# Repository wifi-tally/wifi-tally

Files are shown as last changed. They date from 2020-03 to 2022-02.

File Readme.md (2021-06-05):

# Open Source Tally Light

vTally is an Open Source Wifi Tally Light based on the ESP8266.

It aims to be affordable without sacrificing reliability and works with most
common video mixers.

Its architecture uses a central Hub that connects the tallies to the video mixer and
allows easy configuration and monitoring.

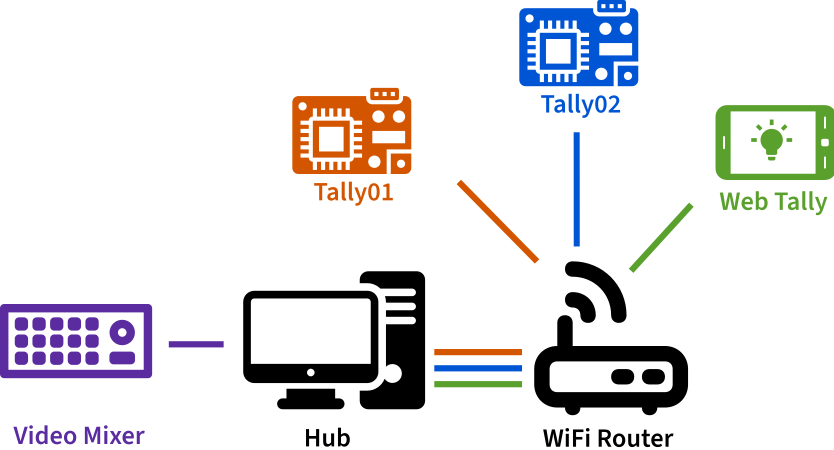
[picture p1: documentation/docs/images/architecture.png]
Architecture Setup

uses icons from the Noun Project by 
[Eucalyp](https://thenounproject.com/browse/?i=3151803),
[Atif Arshad](https://thenounproject.com/browse/?i=1294543),
[priyanka](https://thenounproject.com/browse/?i=1637910),
[Hrbon](https://thenounproject.com/browse?i=3014911) and
[ProSymbols](https://thenounproject.com/browse/?i=1086042), all licensed [CC-BY-3.0](https://creativecommons.org/licenses/by/3.0/us/legalcode)

## Features

* WiFi Tally Light based on the ESP8266
* Hardware costs of about 10€
* flexible USB power (battery pack, camera outlet, stationary)
* Fast communication and lightweight protocol
* uses a central Hub to communicate, that allows easy monitoring
* utilizes your local network and access points
* support for RGB Leds (anode, cathode), WS2812, NeoPixel, etc
* alternatively: turn any device with a browser (smartphone, tablet) into a Tally
* Open Source / Open Hardware

## Getting Started

:arrow_forward: :arrow_forward: :arrow_forward: [Read the full documentation at wifi-tally.github.io](https://wifi-tally.github.io/) :arrow_backward: :arrow_backward: :arrow_backward:

## Status







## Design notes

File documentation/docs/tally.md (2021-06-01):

# Tally

## tally-settings.ini Reference

| setting name | default | description |
| --- | --- | --- |
| `station.ssid` | **(required)** |The name of the WiFi that the Tally should connect to |
| `station.password` | (none) | The password to connect to the WiFi. If the WiFi has no password, leave it empty. |
| `hub.ip` | **(required)** | The IP address the hub is running on |
| `hub.port` | `{{ tally_default_port }}` | The port where the hub listens. |
| `tally.name` | (chip id) | How you want _this_ tally to be labeled in the hub. This name needs to be unique amongst all tallies in your network. It must not be longer than `26` characters. Use of ASCII characters is recommended. |
| `operator.type` | `grb+` | How the pins for the operator light are driven. Use `grb+` when a `high` state signalizes _off_ and `grb-` when a `low` state signalizes _off_. |
| `operator.ws2812` | `5 grb` | Number of WS2812 like LEDs in a strip that serve as operator lights. Has to be a number between `0` and `10`, followed by the order of the colors (`grb` or `rgb`). The operator lights are the first in the strip, followed by the stage lights. |
| `stage.type` | `grb+` | How the pins for the stage light are driven. Use `grb+` when a `high` state signalizes _off_ and `grb-` when a `low` state signalizes _off_. |
| `stage.ws2812` | `0 grb` | Number of WS2812 like LEDs in a strip that serve as stage lights. Has to be a number between `0` and `10`, followed by the order of the colors (`grb` or `rgb`). The stage  lights come right after the operator lights in the strip. |

## Using WS2812, NeoPixel, etc

WS2812-compatible LED strips come with many names. Most common are `WS2812b` and `NeoPixel`. If you have
anything that says it is compatible with either of those, it will probably work.

Connect the strip to pin `D4`, the `+5V` and `GND` respectively.

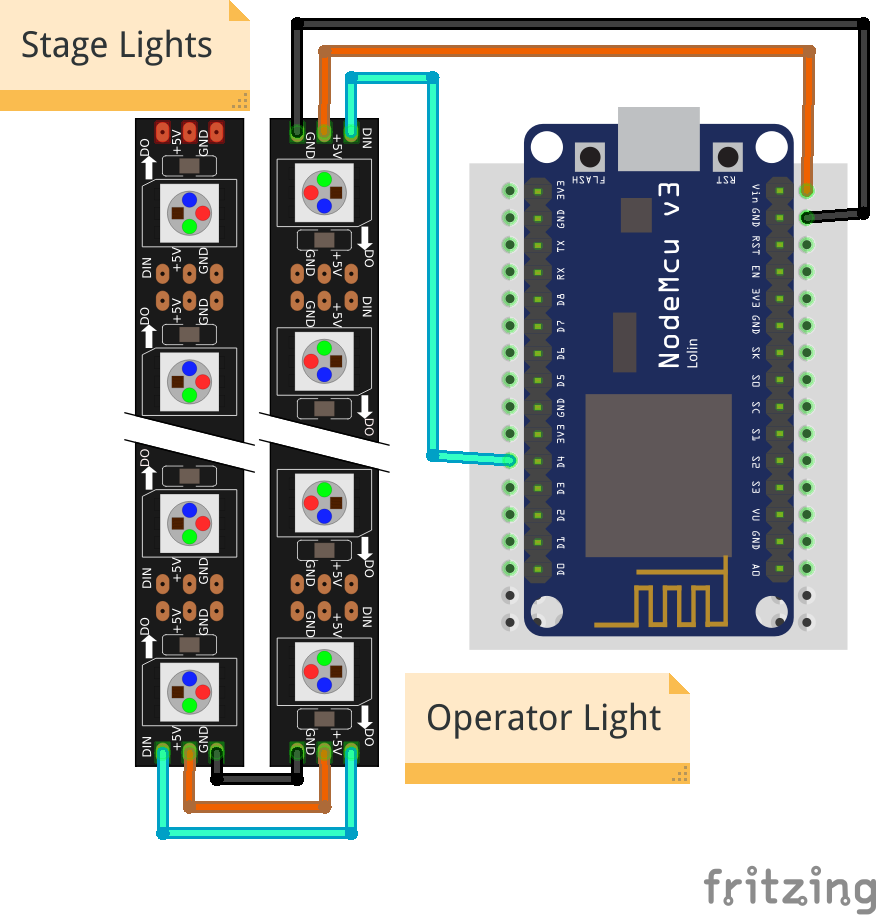
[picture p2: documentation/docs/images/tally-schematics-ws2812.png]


By default the first `5` pixels in the strip will work as Operator Lights, the others stay dark.

The number of LEDs you want to use as Operator Lights and Stage Lights can be configured in 
`tally-settings.ini` with the `operator.ws2812` and `stage.ws2812` settings.

In the example above, the correct configuration to drive 4 Operator Lights and 4 Stage Lights
would be

````ini
operator.ws2812 = 4
stage.ws2812    = 4
````

!!! info "Order of LED lights"
    When wiring, please note, that the Operator Lights always come _before_ the Stage Lights.

It is also possible to combine WS2812 strips and RGB Leds in one setup as all pins are driven
simultaneously. You could, for instance use a single RGB LED as the operator light and a
WS2812 strip for the stage light.

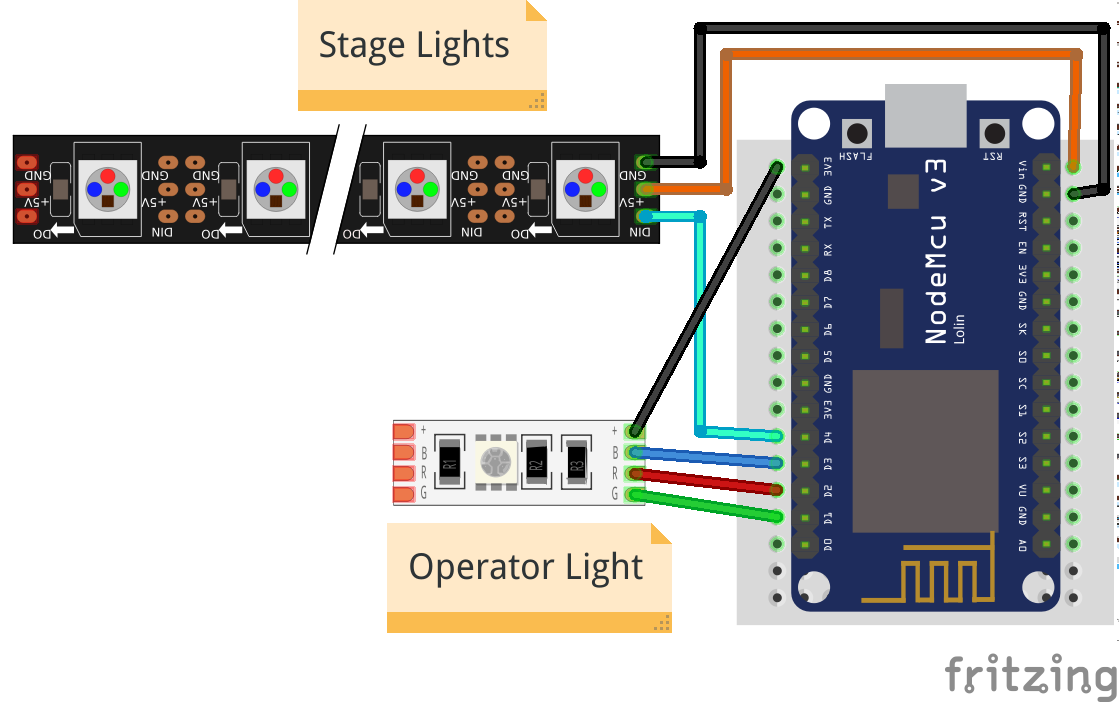
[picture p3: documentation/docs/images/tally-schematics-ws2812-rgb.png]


The configuration for this example would be

````ini
operator.ws2812 = 0
stage.ws2812    = 4
````

## Using LEDs with common cathode

You can use an LED with a common cathode with the tally. First connect the common pin
to `GND` instead of `3V3` and then configure `tally-settings.ini` to drive the pins correctly.
If you skip this step the colors that should be on are off, and vice versa.

````ini
operator.type = grb-
stage.type    = grb-
````

You can also mix different RGB Led types for the Operator and Stage Light.

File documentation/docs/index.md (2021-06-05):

# Open Source Tally Light

vTally is an Open Source Wifi Tally Light based on the ESP8266.

It aims to be affordable without sacrificing reliability and works with most
common video mixers.

Its architecture uses a central Hub that connects the tallies to the video mixer and
allows easy configuration and monitoring.

Architecture Setup
<span style="font-size:smaller;opacity:0.8">uses icons from the Noun Project by 
[Eucalyp](https://thenounproject.com/browse/?i=3151803),
[Atif Arshad](https://thenounproject.com/browse/?i=1294543),
[priyanka](https://thenounproject.com/browse/?i=1637910),
[Hrbon](https://thenounproject.com/browse?i=3014911) and
[ProSymbols](https://thenounproject.com/browse/?i=1086042), all licensed [CC-BY-3.0](https://creativecommons.org/licenses/by/3.0/us/legalcode)</span>

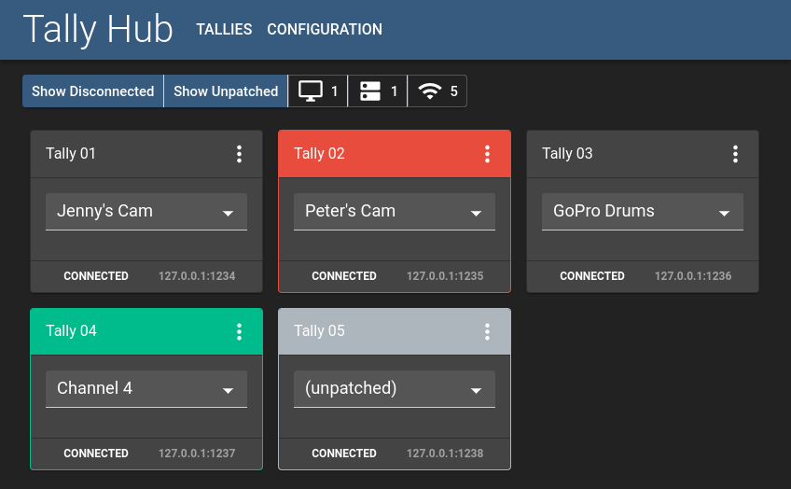
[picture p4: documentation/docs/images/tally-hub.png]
Tally Hub


## Features

* WiFi Tally Light based on the ESP8266
* Hardware costs of about 10€
* flexible USB power (battery pack, camera outlet, stationary)
* Fast communication and lightweight protocol
* uses a central Hub to communicate, that allows easy monitoring
* utilizes your local network and access points
* support for RGB Leds (anode, cathode), WS2812, NeoPixel, etc
* alternatively: turn any device with a browser (smartphone, tablet) into a Tally
* Open Source / Open Hardware

## Supported Video Mixers

* [Blackmagic Design ATEM](https://www.blackmagicdesign.com/products)
* [OBS Studio](https://obsproject.com/)
* [Roland V-8HD](https://proav.roland.com/de/products/v-8hd/), [Roland V-60HD](https://proav.roland.com/de/products/v-60hd/), and maybe others
* [vMix](https://www.vmix.com/software/)

!!! info
    Please [open an issue](https://github.com/wifi-tally/wifi-tally/issues)
    if you want others to be supported too. It is really simple to integrate them
    and the only reason they have not been integrated yet, is that nobody has needed it already. :D

## Get Started

Refer to [Getting Started](getting-started/index.md) to start running your own vTally setup.

## Download

See the [download page](download.md).

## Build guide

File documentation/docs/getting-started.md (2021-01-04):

# Getting started

You need two parts to get the Tally Light operational: The Tally Lights themselves
and the Hub that connects your video mixer and the Tallies.

Architecture Setup
<span style="font-size:smaller;opacity:0.8">uses icons from the Noun Project by 
[Eucalyp](https://thenounproject.com/browse/?i=3151803),
[Atif Arshad](https://thenounproject.com/browse/?i=1294543),
[Hrbon](https://thenounproject.com/browse?i=3014911) and
[ProSymbols](https://thenounproject.com/browse/?i=1086042), all licensed [CC-BY-3.0](https://creativecommons.org/licenses/by/3.0/us/legalcode)</span>

## Things you need

### a trusted network that allows access via WiFi
  
Your video mixer, the Hub and the Tallies need to be able to connect to each other.
You should take care that there is a close and stable WiFi hotspot near your Tallies
for obvious reasons. The network you are using should be trusted as all communication
is unencrypted.

The WiFi Chip supports `IEEE 802.11 b/g/n` and operates in the `2.4GHz` frequency band.
The Wifi network should support that as well.

### a computer to run the Hub on
  
The application is rather light weight, so there are no special requirements here
and it could run other applications in parallel. The Hub has a web interface for
monitoring and configuration that can be shown on any browser that can connect to
the computer.

To keep latency to a minimum it would be perfect if this computer uses a wired
connection.
  
### a NodeMcu ESP8266
  
This is an ESP8266 wifi chip on a development board that is typically used for IoT
applications. As it is an Open Hardware project there are lots of different boards
available. They mostly differ in price and form factor and are all fit for the project.
But they all look similar to this:

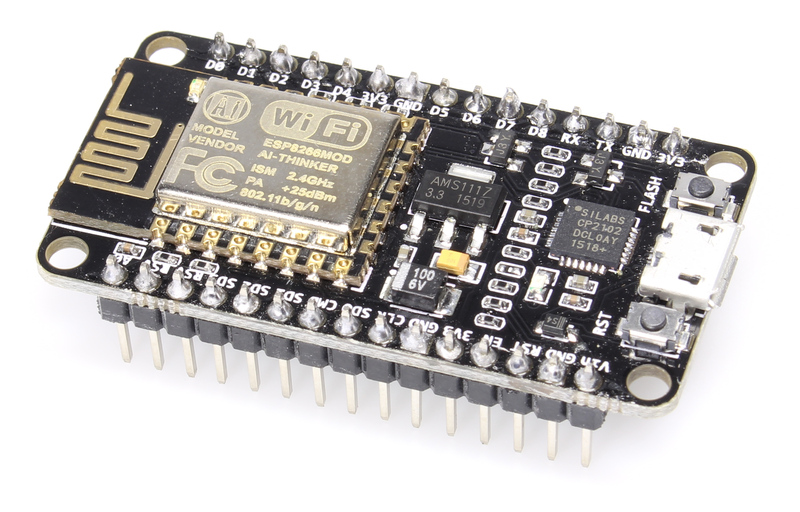
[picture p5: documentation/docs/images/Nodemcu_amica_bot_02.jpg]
Photography of a NodeMCU


["NodeMCU Amica"](https://commons.wikimedia.org/wiki/File:Nodemcu_amica_bot_02.png) 
by "Make Magazin DE", [CC-BY-SA-4.0](https://creativecommons.org/licenses/by-sa/4.0/deed.en)

!TODO: elaborate on different NodeMCUs!
  
### a piece of RGB LED strip
  
It needs to be specified for 5V and have a common anode.
Most LED strips that can be separated after _every_ LED and have 4 pins should fulfill that requirement. 

I recommend taking one with 120LEDs per meter to not have the LEDS be spaced too much.

### an USB power source

The whole setup draws far less than `200mA` and can be powered via USB.

* Some cameras have USB outlets that you can use
* `200mA` is little enough that even the smallest power bank can supply the Tally for hours
* use any old USB charger

## Setup

Running the tally lights consists of two steps:

* **Setup the Tally Light** This means connecting the hardware and flashing the software onto it.

* **Setup the Hub** This is the piece of software that communicates with your video mixer and all
  connected Tallies and runs on any computer you provide.

### Download sources

The latest releases can be found on [github.com/wifi-tally]({{ github_link }}/releases).

### Setting up the Tally

#### Connect the hardware

All you need to do is connecting the LED strip to the NodeMCU board.

!!! warning
    Do not connect more than 5 LEDs to the board!
    
    This will drain too much current through the board and potentially damaging it.

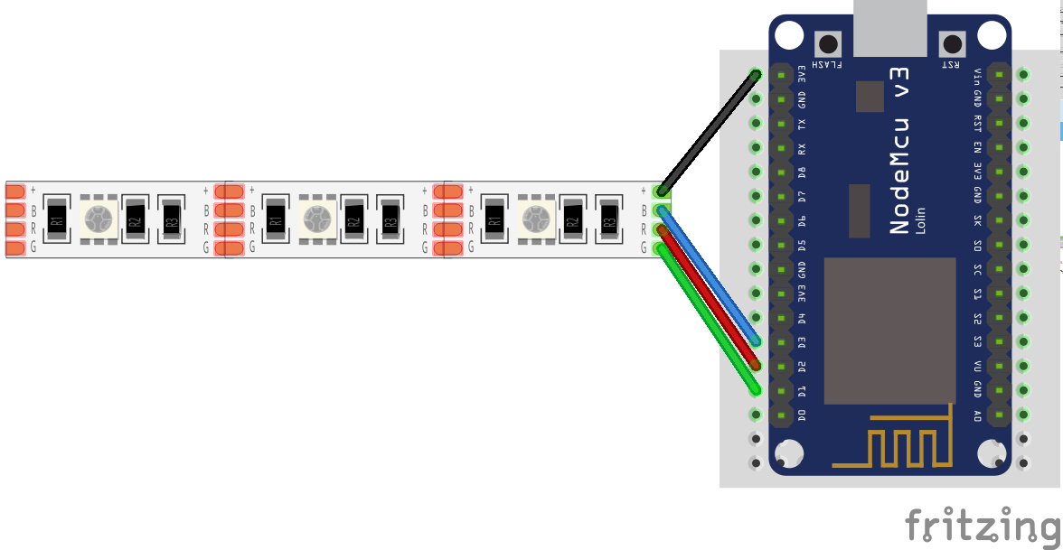
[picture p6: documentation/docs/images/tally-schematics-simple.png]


| board PIN | strip PIN |
| --- | --- |
| D3 | B |
| D2 | R |
| D1 | G |
| 3V3 | + or +5V |

!!! info
    It is possible to connect the `+5V` pin of the LED strip to `Vin` on the board. But not all NodeMCU boards connect
    the PIN to the USB power supply and your LEDs would stay dark.
    
    It might also happen that you LED Strip does not work with a lower voltage of the 3.3V output. Typically this does
    not happen, but it could if you have an older strips.

This is how the setup could look like on a breadboard.

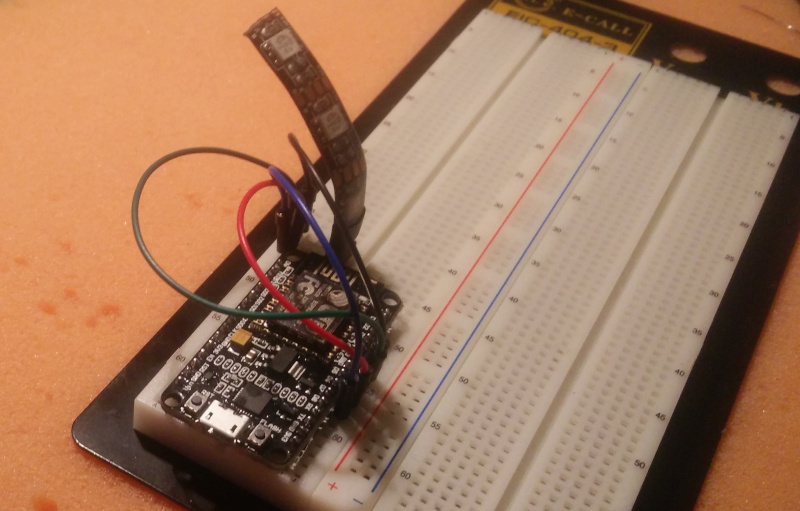
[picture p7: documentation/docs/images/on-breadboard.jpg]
WiFi Tally on a breaboard


##### Separate Operator and Stage Light

You can connect a second strip to use as an indicator for the speaker on stage.
Connect the first LED as above and direct it in the direction of the camera operator.
Then connect a second strip and let it face to the front of the camera. 

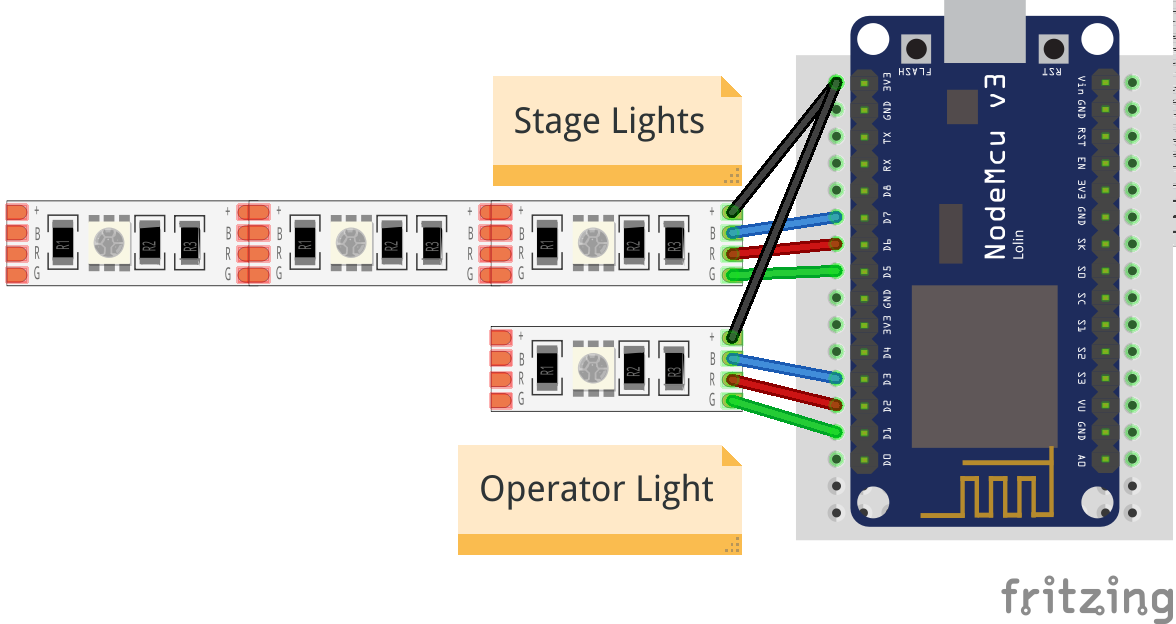
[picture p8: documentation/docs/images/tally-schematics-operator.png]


| board PIN | strip PIN |
| --- | --- |
| D7 | B |
| D6 | R |
| D5 | G |
| 3V3 | + or +5V |

This light will only show preview and live states, but not any error states.
 
#### Prepare the NodeMCU Toolchain

The NodeMCU documentation very nicely explains all the steps necessary to [start a NodeMCU project](https://nodemcu.readthedocs.io/en/master/getting-started/#getting-started-aka-nodemcu-quick-start).
The documentation might seem overwhelming at first, but you only need to care of the two steps

* Flash Firmware, and
* Upload code

Depending on your Operating System, you should select one – and only one – [tool for each of these steps from
the table](https://nodemcu.readthedocs.io/en/master/getting-started/#task-os-selector).

So either select [NodeMCU PyFlasher](https://nodemcu.readthedocs.io/en/master/getting-started/#nodemcu-pyflasher)
or [esptool.py](https://nodemcu.readthedocs.io/en/master/getting-started/#esptoolpy) to flash the firmware
and follow their installation instruction. Similarly select [ESPlorer](https://nodemcu.readthedocs.io/en/master/getting-started/#esplorer)
or [NodeMCU Tool](https://nodemcu.readthedocs.io/en/master/getting-started/#nodemcu-tool) to upload code and follow
their installation instruction.

#### Flash the firmware

When everything is set up flash the firmware with the tool selected in the previous step.

The firmware is the `.bin` file in the `firmware` folder.

#### Upload Code

Use the tool you have selected to upload the following files from the `tally` folder to the NodeMCU board:

* every file ending in `.lc`
* `init.lua`
* the `tally-settings.ini` described below

!!! info "tally-settings.ini"
    This file configures your Tally. You can copy `tally-settings.ini.example` over and edit it as needed.

    | setting name | description | 
    | --- | --- |
    | `station.ssid` | The name of the WiFi that the Tally should connect to |
    | `station.password` | The password to connect to the WiFi. If the WiFi has no password, leave it empty. |
    | `hub.ip` | The IP address the hub is running on |
    | `tally.name` | How you want _this_ tally to be labeled in the hub. This name needs to be unique amongst all tallies in your network. It must not be longer than `26` characters. Use of ASCII characters is recommended. |

    For a list for all configuration values see [tally-settings.ini Reference](tally.md).

Reboot the NodeMCU board by pressing the `RST` button on the board or disconnecting it from power briefly.

!!! success
    If the LED strip starts blinking blue, this means you have correctly connected the hardware, flashed the firmware
    and uploaded the code.
    
    **Well done!** 

### Setting up the hub

The hub requires [node.js](https://nodejs.org/en/) to run. Packages for Linux, MacOS and even Windows
are offered on the [Download page](https://nodejs.org/en/download/). Get version `{{ hub_nodejs_version }}`.

Open the terminal of your operating system, enter the `hub` directory and run

````bash
npm run start
````

!TODO: explain environment variables!

Point your browser to the IP of your computer on port {{ hub_default_port }}, for instance http://127.0.0.1:{{ hub_default_port }} if
you are on the same machine. You should see a screen similar to this

Tally Hub

Your Tallies should also start popping up there. If not see the [Troubleshooting Guide](troubleshooting.md). 

Select `Configuration` in the navigation and configure the settings for your Video Mixer.

Switch back to `Tallies` in the navigation and assign the video channels of the Video Mixer to the according
tallies.

!!! info
    The Tallies and their assigned channels are automatically saved in `.wifi-tally.json` in your home directory.
    So the configuration is restored when the Hub is restarted. 

!!! success
    Your Tallies should start showing green, when they are in Preview and red when they are in Program.
    
    Congratulations, you made it.

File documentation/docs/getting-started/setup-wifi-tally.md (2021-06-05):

# Build and set up a WiFi Tally

The WiFi Tally is a piece of hardware that connects to the Hub via WiFi.

You do not need any prior experience with hardware projects as this is really
beginner friendly.

!!! info
    Please note that this is the Getting Started Guide, and we follow *one* opinionated
    path here. We don't want to confuse new readers with too many options and alternate paths
    to choose from. If you are curious about alternatives, check out details in the 
    [reference](../tally.md).

## Requirements

You need a few parts to build the WiFi Tally.

### a NodeMcu ESP8266
  
This is an ESP8266 wifi chip on a development board that is typically used for IoT
applications. As it is an Open Hardware project there are lots of different boards
available. They mostly differ in price and form factor and are all fit for the project.
But they all look similar to this:

Photography of a NodeMCU

["NodeMCU Amica"](https://commons.wikimedia.org/wiki/File:Nodemcu_amica_bot_02.png) 
by "Make Magazin DE", [CC-BY-SA-4.0](https://creativecommons.org/licenses/by-sa/4.0/deed.en)

!TODO: elaborate on different NodeMCUs!
  
### a piece of RGB LED strip
  
It needs to be specified for 5V and have a common anode.
Most LED strips that can be separated after _every_ LED and have 4 pins should fulfill that requirement. 

I recommend taking one with 120LEDs per meter to not have the LEDS be spaced too much.

### an USB power source

The whole setup draws far less than `200mA` and can be powered via USB.

* Some cameras have USB outlets that you can use
* `200mA` is little enough that even the smallest power bank can supply the Tally for hours
* use any old USB charger

## Connect the hardware

All you need to do is connecting the LED strip to the NodeMCU board.

!!! warning
    Do not connect more than 5 LEDs to the board!
    
    This will drain too much current through the board and potentially damaging it.

connection of the parts

| board PIN | strip PIN |
| --- | --- |
| D3 | B |
| D2 | R |
| D1 | G |
| 3V3 | + or +5V |

!!! info
    It is possible to connect the `+5V` pin of the LED strip to `Vin` on the board. But not all NodeMCU boards connect
    the PIN to the USB power supply and your LEDs would stay dark.
    
    It might also happen that you LED Strip does not work with a lower voltage of the 3.3V output. Typically this does
    not happen, but it could if you have an older strips.

This is how the setup could look like on a breadboard.

WiFi Tally on a breaboard

### Separate Operator and Stage Light

You can connect a second strip to use as an indicator for the speaker on stage.
Connect the first LED as above and direct it in the direction of the camera operator.
Then connect a second strip and let it face to the front of the camera. 

connection of the parts

| board PIN | strip PIN |
| --- | --- |
| D7 | B |
| D6 | R |
| D5 | G |
| 3V3 | + or +5V |

This light will only show preview and live states, but not any error states.
 
## Prepare the NodeMCU Toolchain

The NodeMCU documentation very nicely explains all the steps necessary to [start a NodeMCU project](https://nodemcu.readthedocs.io/en/master/getting-started/#getting-started-aka-nodemcu-quick-start).
The documentation might seem overwhelming at first, but you only need to care of the two steps

* Flash Firmware, and
* Upload code

Depending on your Operating System, you should select one – and only one – [tool for each of these steps from
the table](https://nodemcu.readthedocs.io/en/master/getting-started/#task-os-selector).

So either select [NodeMCU PyFlasher](https://nodemcu.readthedocs.io/en/master/getting-started/#nodemcu-pyflasher)
or [esptool.py](https://nodemcu.readthedocs.io/en/master/getting-started/#esptoolpy) to flash the firmware
and follow their installation instruction. Similarly select [ESPlorer](https://nodemcu.readthedocs.io/en/master/getting-started/#esplorer)
or [NodeMCU Tool](https://nodemcu.readthedocs.io/en/master/getting-started/#nodemcu-tool) to upload code and follow
their installation instruction.

Download [vtally-{{ latest_version }}-esp8266.zip]({{ github_link }}/releases/download/{{ latest_version }}/vtally-{{ latest_version }}-esp8266.zip)
for the latest files for the ESP8266.

## Flash the firmware

When everything is set up flash the firmware with the tool selected in the previous step.

The firmware is the `.bin` file in [vtally-{{ latest_version }}-esp8266.zip]({{ github_link }}/releases/download/{{ latest_version }}/vtally-{{ latest_version }}-esp8266.zip).

## Upload Code

Use the tool you have selected to upload the following files from
[vtally-{{ latest_version }}-esp8266.zip]({{ github_link }}/releases/download/{{ latest_version }}/vtally-{{ latest_version }}-esp8266.zip)
to the NodeMCU board:

* every file ending in `.lc`
* `init.lua`
* the `tally-settings.ini` described below

!!! info "tally-settings.ini"
    This file configures your Tally. You can copy `tally-settings.ini.example` over and edit it as needed.

    | setting name | description | 
    | --- | --- |
    | `station.ssid` | The name of the WiFi that the Tally should connect to |
    | `station.password` | The password to connect to the WiFi. If the WiFi has no password, leave it empty. |
    | `hub.ip` | The IP address the hub is running on |
    | `tally.name` | How you want _this_ tally to be labeled in the hub. This name needs to be unique amongst all tallies in your network. It must not be longer than `26` characters. Use of ASCII characters is recommended. |

    For a list for all configuration values see [tally-settings.ini Reference](../tally.md).

Reboot the NodeMCU board by pressing the `RST` button on the board or disconnecting it from power briefly.

!!! success
    If the LED strip starts blinking blue, this means you have correctly connected the hardware, flashed the firmware
    and uploaded the code.
    
    After a few seconds it should show up in the Hub. Configure a channel there and the WiFi Tally should follow it.
    
    **Well done!** 

!!! info
    If you run into problems, the [Troubleshooting Guide](../troubleshooting.md) should have you covered.

## Conclusion

This concludes the [Getting Started Guide](index.md).

To learn of other options for the Tally Light, see the [reference](../tally.md).

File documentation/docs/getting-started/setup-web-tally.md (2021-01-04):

# Set up a Web Tally

A Web Tally is a Tally Light that runs in a browser.

It can convert any smartphone, tablet or anything with a modern browser into a Tally Light without
much effort.

Further down, we elaborate [when and when **not** to use](#pros-cons) Web Tallies, and you should rely
on WiFi Tallies.

But for now a Web Tally is good enough. Let's see the system in action.

## Setup

You should have already [set up the Hub](setup-hub.md). In the web interface click the "Create Web Tally" button
and create a Web Tally and select a channel from your video mixer it should follow. 

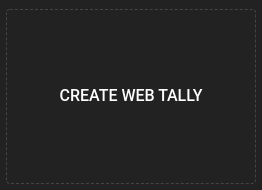
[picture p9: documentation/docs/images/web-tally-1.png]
Button labeled "Create Web Tally"


You can now connect to that Tally from the menu, by clicking "Connect".

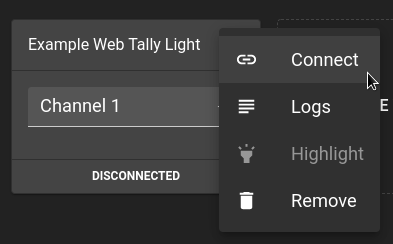
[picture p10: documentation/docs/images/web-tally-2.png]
Button labeled "Connect"


And that's it. Your Tally Light should follow the Video Mixer input. 

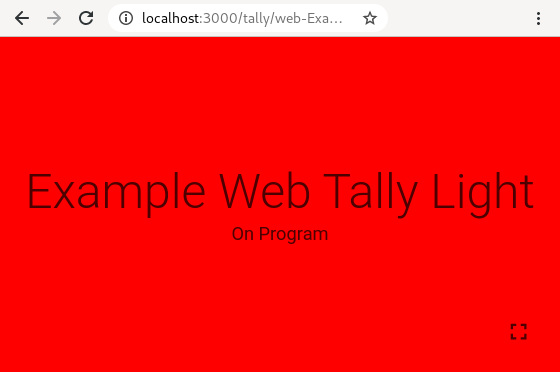
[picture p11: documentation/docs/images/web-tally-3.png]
Web Tally showing "Live" state


!!! info
    We recommend turning adaptive brightness off for devices.
    
    If the browser supports it, screen lock will be disabled when going into full screen.

!!! info
    The url in your browser's address bar can be bookmarked.

## Pros & Cons

### Why to use a Web Tally

* **No additional parts** needed. You already have everything to run it.
* **Having a Web Tally** is better than not having *any* Tally. :D
* Handy for **video material** produced on a **computer**. The Tally Light can be placed anywhere on the screen.

### Why not to use a Web Tally

* **Latency** of a Web Tally is above a WiFi Tally.
* **Form factor** depends on your use case, but a smartphone on top of a camera might be clunky.
* **Network Spam & Distraction**. When using your network for other production-critical applications, like JACK, Art-Net or Dante,
  you might not want a – probably private – smartphone in the same network. It might install updates or show
  an instant messenger notification at the worst possible moment.
* **Easy to use** Once a WiFi Tally is configured, you just need to power it and it is ready to work.

## Conclusion

If you want, go to the next step to learn how to [build and setup a WiFi Tally](setup-wifi-tally.md).
We highly recommend you do it.

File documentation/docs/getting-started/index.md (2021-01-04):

# Getting started

You need two parts to get the Tally Light operational: The Tally Lights themselves,
and the **Hub** that connects your video mixer and the Tallies.

For the Tally Lights you can either build a **WiFi Tally Light** based on NodeMCU
or use a smartphone, tablet, etc to build a **Web Tally**. It is recommended to build
a WiFi Tally Light, as its latency is lower, and they are easier to mount on cameras. But
Web Tallies are a great way to get started with just a smartphone, and can be easily used
for videos inputs coming from a computer, like lower thirds, graphics, etc.

Architecture Setup
<span style="font-size:smaller;opacity:0.8">uses icons from the Noun Project by 
[Eucalyp](https://thenounproject.com/browse/?i=3151803),
[Atif Arshad](https://thenounproject.com/browse/?i=1294543),
[priyanka](https://thenounproject.com/browse/?i=1637910),
[Hrbon](https://thenounproject.com/browse?i=3014911) and
[ProSymbols](https://thenounproject.com/browse/?i=1086042), all licensed [CC-BY-3.0](https://creativecommons.org/licenses/by/3.0/us/legalcode)</span>

## Steps

0. Download the latest release [{{ latest_version }}]({{ github_link }}/releases/tag/{{ latest_version }}) and unpack
0. [Setup the Hub](setup-hub.md)
0. Setup the Tallies.
    
    You can do either of those. It is recommended to start with the Web Tally to get
    evaluate the system, but switch to WiFi Tallies in the long run
    
    0. [Setup a Web Tally](setup-web-tally.md)
    0. [Build and setup a WiFi Tally](setup-wifi-tally.md)

## Network Requirements

Your video mixer, the Hub and the Tallies need to be able to connect to each other.
You should take care that there is a close and stable WiFi hotspot near your Tallies
for obvious reasons. The network you are using should be trusted as all communication
is unencrypted.

The WiFi Chip supports `IEEE 802.11 b/g/n` and operates in the `2.4GHz` frequency band.
The WiFi network should support that as well.

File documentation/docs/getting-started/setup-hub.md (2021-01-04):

# Set up the hub

## Requirements

You need a computer that runs the Hub.

The application is rather lightweight, so there are no special requirements here
and it could run other applications in parallel. The Hub has a web interface for
monitoring and configuration that can be shown on any browser that can connect to
the computer.

To keep latency to a minimum it would be perfect if this computer uses a wired
connection.

## Setup

The hub requires [node.js](https://nodejs.org/en/) to run. Packages for Linux, MacOS and even Windows
are offered on the [Download page](https://nodejs.org/en/download/). We support the latest LTS version,
which should be `{{ hub_nodejs_version }}` at the moment.

Open the terminal of your operating system, enter the `hub` directory and run

````bash
npm run start
````

Point your browser to the IP of your computer on port {{ hub_default_port }}, for instance http://127.0.0.1:{{ hub_default_port }} if
you are on the same machine. You should see a screen similar to this

Tally Hub

Select `Configuration` in the navigation and configure the settings for your Video Mixer.

!!! info
    The Tallies, their assigned channels and your configuration are automatically saved in `.wifi-tally.json`
    in your home directory. So the configuration is restored when the Hub is restarted. 

## Conclusion

When done, go to the next step to [set up a Web Tally](setup-web-tally.md).

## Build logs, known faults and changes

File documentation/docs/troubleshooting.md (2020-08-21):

# Troubleshooting

The Troubleshooting Guide lists a few common symptoms and possible ways to resolve them.
The hints are usually ordered from most likely to least likely.

## After powering the Tally the LED strip stays dark

If the LED strip started flashing blue before turning black, see [below](#the-led-strip-started-flashing-blue-for-a-while-but-then-turned-black).

* Is the Tally really powered? Is your battery pack empty? Could the connector cable be broken?
* Did you upload all files to the Tally?
* Is the LED strip correctly wired?
* Is the LED strip working? Try to connect it to a 5V power source directly.
* Are you using an LED strip with common cathode? Connect the common pin to `GND` and
  [do the necessary configuration](tally.md#using-leds-with-common-cathode).
* Is the NodeMCU working? Try to connect to it via USB
* In case you are developing the Tally Code: It is normal the strip stays black, because the
  `init.lua` file is not uploaded.

## The LED strip started flashing blue for a while but then turned black

* The Tally should usually recover from any errors and reboot automatically. But you could
  try reconnecting it to its power source to reboot it
* The Stage Light stays black when the Tally is not patched in the Hub or not currently on
Preview or Program on the Video Mixer. So this could be totally normal.

## The Tally slowly blinks blue for an extended amount of time

 

**This indicates issues when trying to connect to your WiFi.** It is perfectly normal to see
this during boot up for a few seconds, but it should not sustain for long.

* Is your WiFi up? Is the signal strong enough near the tally?
* Did you configure the WiFi name and its credentials correctly in `tally-settings.ini`?
* Connect to the Tally via USB. It should log an error code why the connection failed.
  The error codes are explained in the [NodeMCU documentation](https://nodemcu.readthedocs.io/en/master/modules/wifi/#wifieventmonreason).

## The Tally blinks blue quickly for an extended amount of time

 

**This means the Tally has connected to your WiFi and is waiting to get an IP address.**
It is perfectly normal to see this during boot up for a seconds, but it should not
sustain for long.

This very likely points to an issue with your WiFi configuration.

* Does your WiFi run DHCP? Are there enough free addresses that your WiFi router could issue?

## The Tally blinks blue twice



**This indicates that the Tally can not connect to the hub.**

* Is the hub running? 
* Is the hubs IP correctly configured in `tally-settings.ini`? Did the IP address of the computer
  running the hub change?
* Could there be a firewall blocking traffic between the Tally and the hub? Communication runs on port `{{ tally_default_port }}` by default.

## The Tally blinks blue three times



**This happens when the `tally-settings.ini` file does not exist or is invalid.**

* Did you flash the `tally-settings.ini` on the Tally?
* Does the `tally-settings.ini` include all mandatory settings?
* Try configuring "wrong" settings that won't work. But this way, you should get a different error and rule out
  that keys where mistyped.

## The Tally blinks blue occasionally

quick blue blinking

**This indicates that the tally is connected to the hub, but the hub does not know
which signal the tally should show.**

* Did the hub connect to your Video Mixer?

## The colors on the LEDs are messed up

* Is the wiring correct?
* It is not unheared of, that the pins of LEDs are not labeled correctly. Maybe switch them around.
* If the colors that should be on are off and vice versa, you probably use an LED with common
  cathode. See the [tally documentation](tally.md#using-leds-with-common-cathode) how to fix it.

## The Hub can not connect to ATEM video mixer

**Are you really sure the settings are correct? If yes read further.**

Every ATEM mixer has a [maximum of connections](https://forum.blackmagicdesign.com/viewtopic.php?f=4&t=101841)
that it allows at the same time – the Internet talks of 3-5 connections depending on the model.
You might be running into this issue.

To verify this as the cause identify all other software / hardware that connects to the Video Mixer,
restart it and make sure the Tally Hub is the first thing to connect.

The way to fix it is very dependent on your setup. See if you can dispense of any
software / hardware connecting to ATEM.

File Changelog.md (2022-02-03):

# v0.5.2

* [BUGFIX] Don't suggest vMix is connected until a hello message is received and tally subscription was acknowledged #85
* [BUGFIX] The logs where written with the path segment `vally-electron`, missing a `t` that is essential to our name. It is now fixed an the files are now:
  * **on Linux**: ~/.config/vtally-electron/logs/main.log
  * **on macOS**: ~/Library/Logs/vtally-electron/main.log
  * **on Windows**: %USERPROFILE%\AppData\Roaming\vtally-electron\logs\main.log

# v0.5.1

* [BUGFIX] Atem did not work when using the Electron distribution #78
* [FEATURE] Improved support when editing scenes in OBS #87 (Thanks, @Fuechschen)
* [FEATURE] When using the Electron distribution, logs are written to a file (please note that the path of the files is wrong in this release and called `vally` instead of `vtally` #93 ):
  * **on Linux**: ~/.config/vally-electron/logs/main.log
  * **on macOS**: ~/Library/Logs/vally-electron/main.log
  * **on Windows**: %USERPROFILE%\AppData\Roaming\vally-electron\logs\main.log

# v0.5.0

Code on the Tally did not change.

* [BREAKING] way of installation has changed. We ship platform specific executables now.
  See [Download Instructions](https://wifi-tally.github.io/download.html) for details.
* [FEATURE] support for Roland V-8HD and V-60HD. Thanks @JWandscheer #58
* [FEATURE] The project got a new name and a logo. Say hello to `vTally` and enjoy the new logo in the GUI.
* [FEATURE] experimental support to edit `tally-settings.ini` and flash the code from the Hub via USB
* [FEATURE] The hub automatically tries to restart in case it crashes. Consider this a safety net: It should never be necessary
  – if it is, please file an issue – but there might be cases where it helps.
* [FEATURE] All releases are published to [npmjs.com](https://www.npmjs.com/package/vtally)

# v0.4.2

A minor feature and maintenance release.

Code on the Tally did not change from `v0.4.1`.

* [ADDED] allow to dim operator light to 1% brightness #57
* [CHANGED] npm dependencies of the hub updated

# v0.4.1

A minor feature and bugfix release.

You only need to update the code on the Tally if you plan on using the new feature
that supports red-green-blue WS2812 light.

* [ADDED] the dim green light for the operator, that indicates the tally is working, can be turned off #50
* [ADDED] support WS2812 leds with red-green-blue order #52
* [CHANGED] npm dependencies of the hub updated
* [BUGFIX] add `init.lua` to the release package. For some reason it got lost along the way

# v0.4.0

**IMPORTANT**: Code on the Tally **HAS** changed. Tallies and the Hub will not be able to communicate
unless you also update the `.lc` files on the Tallies.

* [BREAKING] The protocol between Tally and Hub has been modified. The hub now sends specific information on what colors to show. This step was necessary because we reached the memory limit on NodeMCU with the newly added features.
* [ADDED] Tallies can use a pink-yellow color scheme to be better distinguishable for people with a red-green weakness (Protanopia, Deuteranopia)
* [ADDED] Tallies can be dimmed and the stage light can be turned off completely
* [ADDED] Tallies have an option to hide preview state on the stage light.
* [ADDED] All of the settings above can be changed for ALL Tallies or on a per-Tally basis.
* [ADDED] OBS support to only show on-air status when actually recording or streaming. The Tally Lights will show up as "in preview" when this is not the case.

# v0.3.0

A feature release.

Code on the Tally did not change. If you are doing an upgrade there is no need to
modify the Tallies.

* [ADDED] The Hub allows to turn any device with a browser into a Tally Light ("Web Tally")
* [CHANGED] We recommend updating Node.js to version `14`. The hub will still run with Node.js `12` in the foreseeable future though.
* [CHANGED] Documentation has been cleaned up and the Getting Started Guide has a different order now

# v0.2.1

* [BUGFIX] Tallies and their configuration are stored again

# v0.2.0

There have been numerous technical changes on the hub and the way the release
is built under the hood. One of the results is, that the release packages are now
significantly smaller. We made sure that nothing broke, but if you spot anything
please report it.

Code on the Tally did not change. If you are doing an upgrade there is no need to
modify the Tallies.

* [ADDED] Support for OBS added #27
* [CHANGED] the release size has been reduced significantly. This should speed up download and extraction by a magnitude
* [CHANGED] replaced the UI framework (from bootstrap to MaterialUI). There are some minor changes in the UI, but the general flow stayed the same
* [CHANGED] npm dependencies of the hub updated
* [OTHER] TravisCI, the service we used to build the release packages, has basically discontinued its Open Source support. So the release is now built with Github Actions. This is nothing that you would see when using the software, but still worth mentioning.

# v0.1.0

* [BREAKING] location where the hub stores its configuration has been changed from `hub/config.json` to `$HOME/.wifi-tally.json` #21
* [BREAKING] Pins for Stage Light have been moved from `D2-D4` to `D1-D3`
* [BREAKING] The firmware is no longer part of the repository and will be built on Travis. If you need a firmware for development, get it from the latest release. #25
* [BREAKING] The firmware needs to be updated as the `ws2812` module was added
* [FIXED] prevent hub from crashing on invalid message #19
* [FIXED] hub does boot even if the configuration is empty
* [ADDED] Support for vMix added #12
* [ADDED] the hub does not use generic channel names (like `Channel 1`) if the video mixer has a name configured
* [ADDED] the channel drop-down in the hub is limited to the number of channels supported by the video mixer
* [ADDED] the web page shows if it has lost connection to the hub and reloads #20
* [ADDED] allow the use of LEDs with common cathode #31
* [ADDED] allow the use of WS2812 strips, NeoPixel and the like #29
* [ADDED] better log if it looks as if Atem rejected a connection #16
* [CHANGED] use cross-env to allow hub to run on windows #18
* [CHANGED] npm dependencies of the hub updated
* [CHANGED] firmware version of the tally updated
* [CHANGED] tallies that are not patched in the hub now do not show the "video mixer not connected" error

# v0.1-alpha4

* [FIXED] Compiled `lc` files in the release are working again. #24
* [ADDED] The hub shows indications if the video mixer is connected. #15

# v0.1-alpha3

* [BREAKING] The tallies name is trimmed to `26` characters.
* [BREAKING] Pinout of the tally was changed. See updated documentation. #5
* [FIXED] Following links on the hub is now possible when using the web interface on the machine that runs the hub #1
* [FIXED] Tally sanitizes its hostname if it contains spaces or is longer than 32 characters
* [ADDED] Tally logs the boot reason when starting. This could help determine if the tally crashed (which it never does of course ;) ) or the wifi signal was lost
* [ADDED] Tally buffers up to 10 log messages if the hub is not available. This helps detecting issues once the wifi connection is re-established.
* [ADDED] A separate LED can be used for the operator light on the tally #2
* [ADDED] the operator light is dimly glowing green when everything is connected, but the camera is neither on preview nor program. #7
* [ADDED] the NodeMCU onboard LED indicates if the board is powered and the code started
* [ADDED] Tally indicates if the settings.ini is invalid by blinking blue #11
* [CHANGED] Tally reconnects faster to wifi (`200ms`) when auth timed out, because it indicates low signal strength
* [CHANGED] Logs are better categorized as info, warning and error

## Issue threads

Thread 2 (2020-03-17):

Independent lights for camera operator and speaker

czenker, 2020-03-17:
It should be possible to have a light for the operator (which also shows error and connection states) and a light for the speaker (without the status lights)

czenker, 2020-03-17:
Documentation is still missing.

czenker, 2020-05-09:
12d66e7fd2ee46eb580ab1bf705c0c8bde6a6991

Closed 2020-05-09.

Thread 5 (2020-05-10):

change pinouts

czenker, 2020-05-10:
The blue pinout of the operator light should be on the same pin as the on-board (usually blue) LED.

This should avoid confusion as it is on right now, when the tally is in preview mode. Also helps debugging issues when the LED strip is not connected correctly.

Closed 2020-05-10.

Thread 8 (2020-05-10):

we need a logo :)

czenker, 2020-05-10:

ruudboon, 2020-11-28:
Maybe we can work together on this. https://github.com/ruudboon/tally-blaster

czenker, 2020-11-28:
Hello and welcome.

> Maybe we can work together on this. https://github.com/ruudboon/tally-blaster

I'd love to see more people and ideas on board. You already have a logo and a case – so consider me envious and intrigued. :laughing: You also have some features implemented that I find quite interesting, like the dimming and a working Access Point configuration. So I am all up for joining forces to give the open source world a reliable and affordable tally light that is just amazing.

As on the logo:

I asked a friend of mine to create a logo, but he is just too busy the last months. The specs I gave him were

* monochrome, so it can be 3d-printed on a (potential) case
* small enough so it can be recognized when used as a browser favicon (32x32 px²)

If you have ideas I am all up for ideas.

ruudboon, 2020-11-28:
@czenker I got a big production this weekend. But let's have a chat somewhere next week to see if our ideas align. Cheers!

czenker, 2020-11-28:
@ruudboon I added an email to my profile (or just the one from the commits) and we will find a place to chat.

Brunsben, 2021-03-12:
I'm not a great graphic artist, but maybe that's an inspiration
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

MrTomek, 2021-03-12:
@czenker  Hi guys, I am willing to add something of my own, once I did a tally with HC-12 transmitters (433Mhz) because they have a greater range than

ruudboon, 2021-04-04:
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

czenker, 2021-05-15:
I felt that the project deserves something better than the generic "WiFi Tally" name along with the logo. So, say Hi to `vTally`:

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

ruudboon, 2021-05-15:
Can you make the new logo available as .svg (vector) for 3d printing?

czenker, 2021-05-15:
> Can you make the new logo available as .svg (vector) for 3d printing?

https://github.com/wifi-tally/wifi-tally/blob/stream-0.5/art/vtally-logo.svg

Will be on main as soon as `v0.5.0` is merged.

Closed 2021-12-28.

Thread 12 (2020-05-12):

support Vmix

czenker, 2020-05-12:
https://www.vmix.com

lainol, 2020-06-05:
love to see this feature!! thank you very much, great work!

czenker, 2020-07-21:
Hey @lainol .

I added support for vMix today. It seems to work rather stable and looks good to me. Do you have a setup where you can give it a try in a real-world scenario?

lainol, 2020-07-22:
Yeah, tomorrow I can try It and leave feedback, thank you so much!

DVEntertainment, 2020-10-14:
I used it in a real world live stream event!
Someone built these tallys and i got to use them, they work great!
I'm planning on writing some buildguides for this. Is there any chance you would post or reference my 3dprint files for the boxes?

If anyone wants to buy pre-printed boxes you can comment on this post ofc (this is not the right place for that i know)

best regards
Daniël

czenker, 2020-10-14:
Hi Daniël

Thanks for confirming that it works in a real life scenario. Now I have peace of mind to close this issue. :smile:

About the build guide and 3d prints: Of course! I love to see what people have built and happy to showcase them. And especially a 3d printable case is missing at the moment. So the more options there are – the better.

Closed 2020-10-14.

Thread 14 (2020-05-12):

Document current drain

czenker, 2020-05-12:
According to some rough estimations the current drain should be below 200mA in the worst case. The typical case should be even lower. But we should meassure some real world values.

When documenting the values the users can make an informed decision on the sizes of their battery packs.

czenker, 2020-07-26:
I meassured with an Amica with 4 LEDs (1 Operator Light and 3 Speaker Lights) as shown in the documentation at `5V`.

Minimum drain was `85mA` during connection - maximum drain `135mA` when in program. So calculating with `200mA` should be sufficient to calculate the power source or battery capacity.

Closed 2020-08-11.

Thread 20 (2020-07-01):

show connection status to the hub and reload web site when it is back

czenker, 2020-07-01:
When the hub crashes, the information on the web site is no longer updated and there is no way to see that this is the case.

It should be indicated that the hub is disconnected and the page should have the up-to-date information once the hub is back online.

Closed 2020-08-15.

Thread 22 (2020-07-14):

Error: The Tally slowly blinks blue for an extended amount of time

gumorassi, 2020-07-14:
Hi, I have a problem and I can't solve it. I loaded all the files correctly, but Tally slowly flashes blue over a long period of time and doesn't stop. I tested it with several different wifi networks and it doesn't work. What could be happening? can you help me? @czenker

Here's what appears on ESPlorer:

NodeMCU 3.0.0.0 built on nodemcu-build.com provided by frightanic.com
	branch: master
	commit: 71a182caa7841cbb478ed90ede526dc881943c80
	release:
	release DTS: 202001061321
	SSL: false
	build type: float
	LFS: 0x15000
	modules: encoder,file,gpio,net,node,pwm2,struct,tmr,uart,wifi
 build 2020-02-06 20:31 powered by Lua 5.1.4 on SDK 3.0.1-dev(fce080e)
[INFO]  booted because of EXTERNAL_RESET
[INFO]  Connect to WiFi Rede_Morassi
E:M 1200
E:M 1200
>

Thank you all.

czenker, 2020-07-14:
Hey @gumorassi

Sure. We will get this figured out.

The `E:M` line points to an issue where there is insufficient memory left during run time. So to strike out a few options:

**Which files did you upload?**
You should use the `.lc` ones from the release package. When uploading the `.lua` files the NodeMCU has to compile them itself which uses up memory and could lead to this error.

Another idea - though very unlikely - is that the memory of your NodeMCU is smaller than it should be.
Remove all files from the NodeMCU, reboot it, open a terminal on the NodeMCU and run
````lua
print(node.heap())
````
It should print something around
````
42648
````
If your number is significantly lower, this might be an issue.

gumorassi, 2020-07-14:
Hey @czenker First of all, thanks for the help.

1st test:
I removed all files, restarted and ran the

print (node.heap ())

Which printed the value of:

42200

2nd test:
I loaded the `.lc` files, before loading the `.lua` files, and the error was different this time:

NodeMCU 3.0.0.0 built on nodemcu-build.com provided by frightanic.com
	branch: master
	commit: 71a182caa7841cbb478ed90ede526dc881943c80
	release:
	release DTS: 202001061321
	SSL: false
	build type: float
	LFS: 0x15000
	modules: encoder,file,gpio,net,node,pwm2,struct,tmr,uart,wifi
 build 2020-02-06 20:31 powered by Lua 5.1.4 on SDK 3.0.1-dev(fce080e)
lua: my-app.lc: bad constant in precompiled chunk
stack traceback:
	[C]: in function 'dofile'
	init.lua:1: in main chunk
	[C]: ?
>

czenker, 2020-07-14:
````
lua: my-app.lc: bad constant in precompiled chunk
````

That's not the most helpful error message I have ever seen. :smile: But I gave it a try and there seems to be something wrong with the distributed `lc` files. I created bug #24 for it as this is obviously _my_ fault.

But coming back to your issue. Ignore the releases for now.

To narrow the problem down further:

* I assume you are using Windows? And "NodeMCU PyFlasher" and ESPlorer as your tools of choice?
* Who is the vendor of the board you are using?
* Can you try a different board? Maybe even by a different vendor? (to rule out a hardware defect)
* Can/Did you try erasing the firmware and flashing from scratch?
* I guess you already smashed the `Reset` button multiple times and the problem persisted? (this should free all memory that could still be blocked by compiling the `lua` files on NodeMCU)

The good news is: I managed to flash something with those tools on Windows that shows symptoms similar to yours (getting stuck and out-of-memory errors). I have no idea if it is caused by the same thing, but it is something I can investigate.

gumorassi, 2020-07-15:
Got it, I think it may be this my-app.lc file that is corrupted.

* Yes, I am using Windows, NodeMCU PyFlasher and ESPlorer. Do you have any better suggestions?

* The vendor of the board is: AMICA

* I have another board from the same vendor and I will test to rule out the possibility of hardware defects.

* Yes, I used "flash_download_tool_v3.8.5" to clean the flash.

* Yes

* I downloaded the package "wifi-tally-v0.1-alpha3.zip" and followed the procedure at" https://wifi-tally.github.io/ "(I installed the firmware first and then added all the .lc files then the .lua and lastly the tally-settings).

I will try "wifi-tally-v0.1-alpha2.zip" to see if I have any success, what do you think?

gumorassi, 2020-07-15:
Sorry for my ignorance in passing the problems to you, maybe in some way that I can't understand very well, I have an initial knowledge, but I believe that together we will succeed.

czenker, 2020-07-20:
Sorry it took me some time to look into the issue with the broken `lc` files in the release.

It is fixed now, so would you mind giving [v0.1-alpha4](https://github.com/wifi-tally/wifi-tally/releases/tag/v0.1-alpha4) a try?

It works for me - and hopefully it does work for you too. There is no need to update the firmware - it has not changed in the release.

kubikrubik21, 2020-07-21:
I was running into the same problem with v0.1-alpha3.

Updated to v0.1-alpha4 yesterday and everything works fine for me now.

gumorassi, 2020-07-23:
@czenker
show, it worked perfectly, congratulations and thank you very much.

Closed 2020-07-23.

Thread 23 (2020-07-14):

Build a case

czenker, 2020-07-14:
Some bare electronics on a breadboard are certainly appealing. But building a nice case around it that can be mounted on a hot shoe also has its benefits.

kubikrubik21, 2020-08-06:
My first tally prototype is ready!

I used a Wemos D1 mini as NodeMCU and built a [case from ebay](https://www.ebay.de/itm/VBESTLIFE-16-Kanal-Drahtloser-Wireless-Flash-Trigger-Set-Blitzausloser-Sender-DE/352991513180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) around it. It needed some modifications, but now is a perfect fit.

Have a look
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

czenker, 2020-08-08:
Wow. This looks amazing!

AlexCruz02, 2021-04-07:
What Is the name of that big led.

AlexCruz02, 2021-04-07:
or the listing to buy it

ruudboon, 2021-04-07:
For anybody who's interested. I'm working on a case that I'm planning to share soon. I used these [leds](https://nl.aliexpress.com/item/32732047818.html?spm=a2g0s.9042311.0.0.42d44c4dGIz4Ce). I will add an USB-B or USB-A chassis because I broke too many usb micro connectors on the NodeMCU.  Besides that it has an GoPro mount that can be easily combined with for example [this](https://nl.aliexpress.com/item/32904947724.html?spm=a2g0s.9042311.0.0.7d784c4dkSdaEB) or [this](https://nl.aliexpress.com/item/4001244560045.html?spm=a2g0s.9042311.0.0.7d784c4dkSdaEB). Waiting for some deliveries to finish this.

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

sisensee, 2021-04-20:
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

This is pretty fantastic!

kubikrubik21, 2021-04-21:
> or the listing to buy it

CQL-410 RGB  / WK

https://www.tme.eu/de/details/cql-410rgb_wk/led-dioden-tht-20mm/polam-elta/cql-410-rgb-wk/

Amenasme, 2021-05-08:
Hi guys, I made this case with a 3d printer, it has room for 3 ws2812b leds for stage and 1 rgb led for operator. Then I diffuse the light by covering it with a transparent resin and some drop of white color (made for resin) . This resin will be colored entirely by the leds so we will see a full colored rectangle, and not only a small light. An hot shoe mount is attached on the bottom side and the usb is accessible on the sideso it can be powered by a power bank. I do not insert a battery inside the case. I prefer them small and lightweight. I power them with cameras usb or small powerbank.

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

AlexCruz02, 2021-06-29:
Files?

AlexCruz02, 2021-07-24:
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

You Can Share the files your 3d printed case

AlexCruz02, 2021-07-24:
puedes subir los archivos para poder imprimirlos

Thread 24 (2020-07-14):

my-app.lc: bad constant in precompiled chunk

czenker, 2020-07-14:
Flashing the `lc` files from the [v0.1-alpha3](https://github.com/wifi-tally/wifi-tally/releases/tag/v0.1-alpha3) release makes NodeMCU fail with the following error after reboot:

````
lua: my-app.lc: bad constant in precompiled chunk
stack traceback:
	[C]: in function 'dofile'
	init.lua:1: in main chunk
	[C]: ?
````

czenker, 2020-07-20:
This was caused by a new release of the nodemcu-firmware. Going back to the latest release solved the issue for now.

But the real fix would be to update the firmware or build the firmware together with the release instead of using a binary.

Closed 2020-07-20.

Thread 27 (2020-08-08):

support OBS

czenker, 2020-08-08:
https://github.com/obsproject/obs-studio

DVEntertainment, 2020-11-10:
Yes please!

marianputsko, 2020-11-16:
Yes, please

czenker, 2020-11-20:
Your voices have been heared. :smile:

I have added OBS support in the recent commits. It requires the [obs websocket plugin](https://github.com/Palakis/obs-websocket) and allows to track all _scenes_ with a tally light.

Could some of you give it a thorough testing with some real-life setup? A nightly build is available here:

  * https://wifi-tally-nightly.s3.eu-central-1.amazonaws.com/wifi-tally-v0.1.0-21-g389a298.zip
  * https://wifi-tally-nightly.s3.eu-central-1.amazonaws.com/wifi-tally-v0.1.0-21-g389a298.tar.gz
  * https://wifi-tally-nightly.s3.eu-central-1.amazonaws.com/wifi-tally-v0.1.0-21-g389a298.tar.xz

As I have not worked with OBS in production, maybe someone can answer me, if it is enough to only allow to select _scenes_  for the tally lights. It allows for Picture In Picture by embedding scenes into one another. But I am not sure how this is typically set up.

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

Have fun and I hope to hear of your experiences. :movie_camera:

DVEntertainment, 2020-11-21:
oh my god you are awesome. I'll test it this weekend!

czenker, 2020-12-21:
@DVEntertainment Any news on this? Did it work out?

marianputsko, 2020-12-21:
Helo.

I stoppt to use OSB, now I use Wirecast.

Thank you.

Prajem pekny den, s pozdravom

Marian Putsko, putsko.com, s.r.o.
Zapotocna 959/45
02801 Trstena, Slovakia

Tel. +421905879107
Mail: marian@putsko.com
------—-----------------------------
www.putsko.com
www.liveproduction.sk
www.selfiebudka.sk
www.knihahosti.sk

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

DVEntertainment, 2020-12-22:
>
>
> @DVEntertainment Any news on this? Did it work out?

I have used it a couple of times, and it never failed on me! Great implementation!

czenker, 2020-12-23:
Great to hear! Thanks for testing it.

Closed 2020-12-23.

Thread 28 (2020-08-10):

Include a 0.91" I2C OLED display

gumorassi, 2020-08-10:
Is it possible to include a 0.91" I2C OLED display to view Tally's IP address and the name assigned to the device?

gumorassi, 2020-08-10:
And in the future who knows even the level of WiFI signal

czenker, 2020-08-11:
Adding the display would almost double the hardware costs of the Tally. :laughing:

Eventhough I think it would be quite informative I fear that it makes the Tally a bit too complex and distracts the camera operator from the thing they should do (generating video footage).

But if you are willing to invest some time in a Pull Request, I will be happy to include it.

Closed 2020-10-05.

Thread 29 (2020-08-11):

add support for WS2812b aka Neopixel LED Strips

flow1986, 2020-08-11:
Would it be possible to add support for the WS2812b LED Strips?
(also known as Adafruit Neopixel)

they are 5 Volt and you can connect them easy to the nodeMCU board with just 3 Pins:
GND, V, Signal...

thanks
Flow

czenker, 2020-08-11:
Hey Flow.

I like the idea. This is also an elegant solution to the problem that we might be draining too much current through the pins.

The only problem I see is that [some boards do not connect the 5V pin to the USB plug](https://arduino.stackexchange.com/a/51878). But I like this as an option nevertheless.

mlcook19, 2020-08-11:
I think this could be a good addition to the platform since 5v LED strip is
getting harder and harder to find.

On Tue, Aug 11, 2020, 11:57 AM Christian Zenker <notifications@github.com>
wrote:

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

czenker, 2020-08-28:
Hey @flow1986 and @mlcook19.

The latest [release 0.1.0](https://github.com/wifi-tally/wifi-tally/releases/tag/v0.1.0) has support for WS2812, if you want to check it out.

I really like it and the strip is sooo much brighter than the LED strip I was using before :sunglasses: – so I will definitely go with this.

Closed 2020-08-28.

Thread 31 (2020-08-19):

allow use of LEDs with common cathode

czenker, 2020-08-19:

czenker, 2020-08-25:
Thanks for the pointer. It makes sense to approach that setting more generally. I cleared it up in the documentation, but left the paragraph about using it with a single common cathode LED in for now.

I think for the future it makes sense to promote WS2812 as the default configuration. It is the easiest to set up from a hardware point of view and requires minimal soldering. And keeping the entrance barrier as low as possible for everyone is one of my main goals. But I would like to give it some time in the field before promoting it as the new way to go.

Driving single LEDs directly from the microcontroller or multiple LEDs via transistors would be supported variations of the default setup then.

Closed 2020-08-19.

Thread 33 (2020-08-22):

LED glowing green in "OnRelease" state

kubikrubik21, 2020-08-22:
I have noticed that my LED was glowing light green in **onRelease** state. Is it what it should be??? Because I was expecting the LED to turn off in this state.

my-led.lua Line 144
`onRelease = flashPattern(".", colors.GREEN, nil, false),`

That means 1% Duty cycle at 1kHz PWM frequency. Thats enough to let the LED glow.

czenker, 2020-08-24:
Yes, this is intentional and was added in 0.1-alpha3 (see #7).

I had the issue that our camera operators did not trust the hardware as much as I did. :laughing: So they sometimes were not sure if there is something wrong with the tally or not. Adding the very dim green light should be clearly distinguishable from the preview state and gives them peace of mind.

kubikrubik21, 2020-08-26:
Makes sense. Thank you for clearing that up 😉

Closed 2020-08-26.

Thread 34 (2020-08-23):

Lua: cannot open my-app.lc

the-observer07, 2020-08-23:
Hey @czenker,

I'm quite new to this, but i used the firmware from 0.1 Alpha4.

Led strip does not light up, onboard led does not light up

**PORT OPEN 115200

Communication with MCU..Got answer! Communication with MCU established.
AutoDetect firmware...

Can't autodetect firmware, because proper answer not received (may be unknown firmware).
Please, reset module or continue.

NodeMCU 3.0.0.0 built on nodemcu-build.com provided by frightanic.com
	branch: master
	commit: 71a182caa7841cbb478ed90ede526dc881943c80
	release:
	release DTS: 202001061321
	SSL: false
	build type: float
	LFS: 0x15000
	modules: encoder,file,gpio,net,node,pwm2,struct,tmr,uart,wifi
 build 2020-02-06 20:31 powered by Lua 5.1.4 on SDK 3.0.1-dev(fce080e)
lua: cannot open my-app.lc
stack traceback:
	[C]: in function 'dofile'
	init.lua:1: in main chunk
	[C]: ?
>**

czenker, 2020-08-24:
Hey @the-observer07.

I'm glad to help. The error looks as if the `my-app.lc` file is not present on NodeMcu. Did you upload all the files ending in `.lc` from the release? It is important to have the files ending in `.lc` (not `.lua`) on the microcontroller.

Hope this helps. If not: what OS are you using? Which tool chain and what NodeMcu maker? That could help narrowing the issue down.

the-observer07, 2020-08-25:
@czenker

I was using windows 10 with pyflasher and esplorer and switched over to using mac os 10.15.5.

I flashed the firmware using NodeMCU.pyflasher and uploaded the files using esplorer and it's now working.

in 0.1 Alpha 4, the files are shown as .lc files; however, in version 0.1 the files all show up as .lua

I've managed to connect it up to the hub and am using a 5vRGB light strip, preview is showing Red and Program is showing Blue on the strip.

the-observer07, 2020-08-25:
I figured out why, in the code GRB is on pins 2,3,4 but on the assembly instructions it's stated at pins 1,2,3.

czenker, 2020-08-25:
Glad, that fixes it for you. About the pins: I changed them a few days back to support `WS2812` - so the documentation reflects that already while the releases do not. But every release comes with a snapshot of the documentation in the documentation folder.

Closed 2020-08-25.

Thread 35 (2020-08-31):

Wemos D1 Mini

gumorassi, 2020-08-31:
Hello @czenker
Is it possible to use a wemos D1 mini?
The curiosity arose for being a smaller size board.

czenker, 2020-08-31:
Yes, it works.

@kubikrubik21 uses it in [his build](https://github.com/wifi-tally/wifi-tally/issues/23#issuecomment-669936670) and all the necessary pins are available. I also just gave the new NeoPixel / WS2812 support a try at home. So you should not have any trouble.

gumorassi, 2020-09-01:
I had a problem loading the firmware, the following message appears on the NodeMCU PyFlasher and it does not go away: "Uploading stub ..."
 What could it be?

czenker, 2020-09-01:
There could be many reasons. :thinking:

First up: What's your experience with microcontrollers? I hope I am not getting too basic here, but these are the things I would consider first:

* it's perfectly normal for the process to take 1-2 minutes. But I don't assume _this_ is your problem.
* Do you use a baud rate of `115200`? Having it lower will increase the upload time significantly. Having it higher could lead to problems.
* Did you install the [driver for the USB-to-Serial chip](https://docs.thingpulse.com/how-tos/install-drivers/)? For the Wemos D1 mini this should be the CH840G.
* Does it behave differently on a different USB port?
* Do you have a different D1 Mini that you can try to rule out hardware defects? Or is it possible to flash a different firmware?
* Disconnect the D1 Mini from any circuitry. Sometimes it can interfere with the upload process.

If nothing helps, please post the full log of PyFlasher here.

Closed 2020-10-05.

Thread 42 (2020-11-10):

How to fix error loading module 'my-wifi' from file 'my-wifi.lc'

PeterThtr, 2020-11-10:
Hello everybody!
I would love get this smart project running and use wifi-tally for our live streaming events.
I made to flash the firmware to my ESP8266 and upload all necessary files (using ESPlorer). But during startup of the ESP8266 (new NodeMcu V3) I always get this "error loading module 'my-wifi'" message. Can somebody please help me fixing this?

Here is the output:

`NodeMCU 3.0.0.0
	branch: HEAD
	commit: 8d091c476edf6ae2977a5f2a74bf5824d07d6183
	release: 3.0-master_20200610
	release DTS: 202006092026
	SSL: false
	build type: float
	LFS: 0x15000 bytes total capacity
	modules: encoder,file,gpio,net,node,pwm2,struct,tmr,uart,wifi,ws2812
 build 2020-08-26 14:11 powered by Lua 5.1.4 on SDK 3.0.1-dev(fce080e)
error loading module 'my-wifi' from file 'my-wifi.lc':
	my-wifi.lc: bad integer in precompiled chunk
stack traceback:
	[C]: ?
	[C]: in function 'require'
	src/my-app.lua:7: in main chunk
	[C]: in function 'dofile'
	init.lua:1: in main chunk
	[C]: ?
> `

Thanks a lot!

Peter

czenker, 2020-11-11:
Hi Peter and welcome.

The error usually points to the problem that the firmware and the version the `lc` files where built with are different.

I assume you used the firmware and the `lc` files from the [latest release](https://github.com/wifi-tally/wifi-tally/releases/tag/v0.1.0). Right? I just gave it a try and it works perfectly for me (on Linux).

What you could try is to download the [source code of the latest release](https://github.com/wifi-tally/wifi-tally/archive/v0.1.0.zip) and let ESPtool compile the included `lua` files. This would not fix the underlying issue, but might help you to continue with your project.

PeterThtr, 2020-11-11:
Hi Christian,

thank you for your quick answer. Yes, I used the lc files from the latest release. Unfortunately this is one level to high for me. I have python installed and the ESPtool up running (on my PC) but I don't know how to compile the lua files on my ESP8266. Is there a how-to you could recommend?

Thanks a lot!

Peter

czenker, 2020-11-11:
Sorry. I wrote _ESPtool_ in my last post, but meant _ESPlorer_.

Don't fret: If you have the firmware on your ESP8266 it can compile lua files for you. ESPlorer has multiple buttons in the bottom left to compile `lua` files into `lc`. Just remember to compile all `lua` files, **except** `init.lua`. It has to be uploaded as is.

PeterThtr, 2020-11-12:
Hi!
I have done it.
Thanks to your hints everything is working smoothly now.
Great project.
Thanks again and best regards!

czenker, 2020-11-14:
:bow:

Closed 2020-11-14.

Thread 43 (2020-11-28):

Support NeoPixel RGB leds

ruudboon, 2020-11-28:
Would be great if we can use NeoPixel led's.

czenker, 2020-11-28:
You already [can](https://wifi-tally.github.io/tally.html#using-ws2812-neopixel-etc).

Or do you plan something different?

ruudboon, 2020-11-28:
Cool, totally missed that. Will give it a shot

ruudboon, 2020-11-28:
Works great.

Closed 2020-11-28.

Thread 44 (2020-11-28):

NFR: Only show live for stage/talent

ruudboon, 2020-11-28:
Often I don't want to distract my talent and want them to focus on red only.
Would it be possible to disable the preview for the stage and give the operator only heads up for the preview?

czenker, 2020-11-28:
With RGB Leds this is easy: Don't connect the green LED. :smile:

But yes, this should become an option at some point.

If you need a quick fix for now, this is the line to change the logic:

https://github.com/wifi-tally/wifi-tally/blob/389a298332b69e7827ea73f586a1c1794fa06051/tally/src/my-led.lua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

czenker, 2021-01-31:
This is part of [v0.4.0](https://github.com/wifi-tally/wifi-tally/releases/tag/v0.4.0)

Closed 2021-01-31.

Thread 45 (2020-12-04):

Support Roland VR-50HD MKII

ruudboon, 2020-12-04:
I would like to request for the Roland VR-50HD MKII

JWandscheer, 2021-04-06:
Sadly it's the third way of getting tally information from Roland devices except from midi and smart tally. It's possible via  sockets - there are already a few implementations out, seems not to be very complicated.
I'm not going to have a VR-50HD MKII mixer here in the near future, is it still necessary to implement support?

leusound, 2021-12-22:
I'm interested to get the VR-50HD MK2 in - how ist the status? Thanks :-)

czenker, 2021-12-29:
No progress as far as I know.

But if you have access to one, that might be a good start. It should be doable, but it is hard without a testing device. If you are willing to contribute or help, it could be possible.

leusound, 2021-12-29:
Hallo Christian
We have vr-50hy mk2, atem mini pro and vmix on our rental stock snd frequently in use. However we are no Software engineers (I’m electrical engineer) We would love to test and assist/support/controbute in a tally option for the vr-50hd mk2. We have on feb. 2nd a large production where we urgently need a tally at least for the canera-operator. Let me know what you think.

Am 29.12.2021 um 14:09 schrieb Christian Zenker ***@***.***>:

No progress as far as I know.

But if you have access to one, that might be a good start. It should be doable, but it is hard without a testing device. If you are willing to contribute or help, it could be possible.

—
Reply to this email directly, view it on GitHub<https://eur02.safelinks.protection.outlook.com/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>, or unsubscribe<https://eur02.safelinks.protection.outlook.com/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>.
Triage notifications on the go with GitHub Mobile for iOS<https://eur02.safelinks.protection.outlook.com/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> or Android<https://eur02.safelinks.protection.outlook.com/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>.
You are receiving this because you commented.Message ID: ***@***.***>

czenker, 2021-12-29:
Hey. That's great. I think, together we can get this thing working.

After reading the documentation and checking a reference implementation I might have a working prototype.

You can install it via npm ([see documentation](https://wifi-tally.github.io/download.html#run-from-npm)) using the following command:

````bash
npm install -g  https://wifi-tally-nightly.s3.eu-central-1.amazonaws.com/vtally-0.5.1-rc1-1-g23ce049/vtally-0.5.1-rc1-1-g23ce049.tgz
````

Contact me via my email address in my profile and I send you my personal contact information. So we can coordinate how to proceed.

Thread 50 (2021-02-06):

Disable power status

ruudboon, 2021-02-06:
Currently the first led when using WS2812 is showing the status. (dimmed green when all good).
Would it be possible to add an option to disable this and leave it all dark?

czenker, 2021-02-06:
Do you want to turn off the operator light completely or just disable the "everything ok, but you are neither on preview nor live"-light?

The first thing can be done with [`operator.ws2812 = 0`](https://github.com/wifi-tally/wifi-tally/blob/master/documentation/docs/tally.md#using-ws2812-neopixel-etc).

ruudboon, 2021-02-06:
Disable the everything ok, nothing switched green status led. When setting the operator led to low intensity the green ok is confused with the preview.

czenker, 2021-02-06:
Added it here: https://wifi-tally-nightly.s3.eu-central-1.amazonaws.com/wifi-tally-v0.4.0-2-ga2907b4.tar.gz

and will be in the next release.

ruudboon, 2021-02-08:
Thnx buddy

Closed 2021-03-11.

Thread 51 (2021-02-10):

Roland V8HD

Brunsben, 2021-02-10:
Hello,
is it possible to support the Roland V8HD too?

ruudboon, 2021-02-10:
I think it has the same protocol as https://github.com/wifi-tally/wifi-tally/issues/45 Will try to borrow a device soon.

Brunsben, 2021-02-22:
Would it help if we log the data traffic on the USB on our V8HD with Wireshark and make it available?

ruudboon, 2021-02-22:
Ah, I assumed it was network connected as well. You could check if a local network is created over the USB port but if that isn't the case it will be harder to implement this.

Brunsben, 2021-02-22:
I'll be back in the club tomorrow. Then I'll see if I can find out anything.

Brunsben, 2021-02-27:
Hey, it seems there is no local network.

Brunsben, 2021-03-06:
A friend told me that it is probably a midi signal.

czenker, 2021-03-10:
@Brunsben Thanks for looking into it. From what I see, an iPad app is the _only_ remote thing that you can connect to the mixer at the moment!?

I'm not expecting too much, but maybe contacting Roland with your problem and asking if they can supply you with a documentation of the serial protocol can help. Explaining that you are interested in implementing a solution, could help going forward. Worst case is that they don't answer. In the best case other open source projects, like Companion, benefit too.

On a side note: I'm currently working on a way to [flash the Tallies from within the Hub via USB](https://github.com/wifi-tally/wifi-tally/tree/flasher). So a serial library will be shipped with the next release anyway, which might help with integrating your Roland V8HD.

Brunsben, 2021-03-18:
> From what I see, an iPad app is the only remote thing that you can connect to the mixer at the moment!?

Yes.

I'll try on Friday with a friend to see if we can somehow get data out of there. He's just doing his master's degree in computer science, maybe he'll get something done.

JWandscheer, 2021-03-21:
Did id. It can be done via Midi, you have to send a SysEx DataRequest Message to the Mixer, it will return the tally status for the requested input (more information in [V-8HD manual](https://static.roland.com/assets/media/pdf/V-8HD_reference_eng03_W.pdf)).
In some other mixers, Roland has a SmartTally function, where the input status can be determined via simple http requests to the mixer (one request per channel needed). I've written a small Python script that basically simulates a SmartTally server, to save http-requests all statuses are always output. Additionally, I added an experimental support for requesting this dummy-server in wifi-tally.
The more elegant solution would be to connect the hub directly to the mixer via USB and read out the midi information directly in the wifi-tally, without going the diversions via another server-script. Think this can be done via [node-midi](node-midi). I will try this in the next few weeks.

czenker, 2021-03-22:
Great work, @JWandscheer! If you need help integrating it into wifi-tally, please ping me.

Closed 2021-12-28.

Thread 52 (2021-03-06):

RGB/GRB WS2812

DVEntertainment, 2021-03-06:
Hi Guys!

I have some GRB ws2812, and as far as i know, there is no way to switch this. This means that my preview is red, and my program is green. A simple switch in the hub would solve the problem!

Thanx!

czenker, 2021-03-09:
Hey.

I have added this as a feature to the `tally-settings.ini` (my thinking being, this is a feature of the tally light itself that you are never required to change if you don't change the hardware) Give it a try here:
https://wifi-tally-nightly.s3.eu-central-1.amazonaws.com/wifi-tally-v0.4.0-4-g103f657.tar.gz

and let me know if it works for you.

czenker, 2021-03-09:
Erm, sorry. Did not want to leave you hanging, but forget the mention I updated the [documentation](https://wifi-tally.github.io/tally.html) on how to do it as well :smile:

`tally-settings.ini` should contain something like:

    operator.ws2812=1 rgb
    stage.ws2812=5 grb

DVEntertainment, 2021-03-10:
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

Yes This is exzactly where i was looking for! Thanx for the update of documentation!
Yes, tally-settings.ini is more than enough.

Closed 2021-03-10.

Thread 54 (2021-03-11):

reactivate temporarily disabled Cypress tests on Windows

czenker, 2021-03-11:
Cypress test currently fail on Windows with Edge: https://github.com/wifi-tally/wifi-tally/actions/workflows/cypress.yml

```
Warning: We failed to record the video.

This error will not alter the exit code.

Error: ffmpeg exited with code 1: Error initializing output stream 0:0 -- Error while opening encoder for output stream #0:0 - maybe incorrect parameters such as bit_rate, rate, width or height
Conversion failed!

    at ChildProcess.<anonymous> (C:\Users\runneradmin\.cache\Cypress\6.6.0\Cypress\resources\app\packages\server\node_modules\fluent-ffmpeg\lib\processor.js:182:22)
    at ChildProcess.emit (events.js:315:20)
    at Process.ChildProcess._handle.onexit (internal/child_process.js:275:12)

    Error: ffmpeg exited with code 1: Error initializing output stream 0:0 -- Error while opening encoder for output stream #0:0 - maybe incorrect parameters such as bit_rate, rate, width or height
Conversion failed!

    at ChildProcess.<anonymous> (C:\Users\runneradmin\.cache\Cypress\6.6.0\Cypress\resources\app\packages\server\node_modules\fluent-ffmpeg\lib\processor.js:182:22)
    at ChildProcess.emit (events.js:315:20)
    at Process.ChildProcess._handle.onexit (internal/child_process.js:275:12)

    Error: ffmpeg exited with code 1: Error initializing output stream 0:0 -- Error while opening encoder for output stream #0:0 - maybe incorrect parameters such as bit_rate, rate, width or height
Conversion failed!

    at ChildProcess.<anonymous> (C:\Users\runneradmin\.cache\Cypress\6.6.0\Cypress\resources\app\packages\server\node_modules\fluent-ffmpeg\lib\processor.js:182:22)
    at ChildProcess.emit (events.js:315:20)
    at Process.ChildProcess._handle.onexit (internal/child_process.js:275:12)
```

The issue is [known](https://github.com/cypress-io/cypress/issues/3491), but [the fix](https://github.com/cypress-io/cypress/pull/15295) has not be released yet. If it is done, we should re-enable the tests on Windows again.

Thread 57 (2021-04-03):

Operator Light Brightness

ruudboon, 2021-04-03:
In theaters I noticed that 20% sometimes is even too bright.
Can we allow to go to 1%? Or to create consistency even go to off like the stage light?

czenker, 2021-04-08:
LEDs and their non-linear dim curve... :laughing: I don't see a problem with decreasing that value.

I would rather not allow to turn the operator light off completely. The Tally should be beginners friendly and turning the operator light off by accident might be very confusing, because the Tally might seem broken. On the other hand I do not see a reason why anyone would want to turn off the operator light completly. As a workaround... any production should have some Gaffer Tape, right? :wink:

ruudboon, 2021-04-08:
1% works for me. Thnx

Closed 2021-05-16.

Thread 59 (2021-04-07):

Deactivate LEDs when idle

Brunsben, 2021-04-07:
Is it possible to deactivate the LEDs when there is no status (not program or preview)?
They are currently green when idle (idle: new Color(0, 1, 0) )

Or a menu item in the settings where you can configure it?

ruudboon, 2021-04-07:
In settings you can disable "Shows Idle State"

Brunsben, 2021-04-07:
Oh, then we must have overturned it, thanks

Closed 2021-04-07.

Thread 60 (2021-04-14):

Not working with Vmix 24.0.0.56

tobiswdec, 2021-04-14:
Vmix 24.0.0.56 isnt working. But OBS is working fine.

Update: Vmix 23.0.0.68 isnt working neither.

Sometimes the hub shows a video mixer connected, but you can not assing any inputs to tallylights.
My ESP8266 Tallylight (Kamera1) showing up in hub succesfully.

Config:
Vmix Version 24.0.0.56
Windows 10 Pro 20H2
Buildnumber: 19042.867

Intel(R) Core(TM) i5-3320M CPU @ 2.60GHz   2.60 GHz, 16GB RAM

npm version
{
  'wifi-tally': '0.4.1',
  npm: '6.14.11',
  ares: '1.16.1',
  brotli: '1.0.9',
  cldr: '37.0',
  icu: '67.1',
  llhttp: '2.1.3',
  modules: '83',
  napi: '7',
  nghttp2: '1.41.0',
  node: '14.16.0',
  openssl: '1.1.1j',
  tz: '2020a',
  unicode: '13.0',
  uv: '1.40.0',
  v8: '8.4.371.19-node.18',
  zlib: '1.2.11'
}

Vmix Config:
http://192.168.120.168:8088/tally

Web-Controller:
Checked: Port 8088
Username: admin
Password: BLANK/unset
Controller, Shortcuts, Titles, Tally, API: all unchecked,
Checked: Without Login

Downloaded via https://github.com/wifi-tally/wifi-tally/releases/tag/v0.4.1 as .zip

Powershell Hub Output:
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

tally-settings.ini:
station.ssid=SWD-EC-IT
station.password=******
hub.ip=192.168.120.168
; default is 7411
hub.port=7411
; How you want your Tally to be known
tally.name=Kamera1
; operator.ws2812 = 1
; stage.ws2812    = 2

Amenasme, 2021-04-29:
the same for me, it doesn't work. web tally doesn't connect

ruudboon, 2021-04-29:
I tried with 24.0.0.57 and didn't noticed any issues. Could you test with 24.0.0.57 as well?

czenker, 2021-04-29:
Also works for me on Win10 Build `19042.928` with NodeJS `14.16.1` and vMix `24.0.0.57`.

The thing that looks strange in your config is the port `8088` used for vMix. Wifi-Tally uses the [TCP Api](https://www.vmix.com/help24/index.htm?TCPAPI.html) on port `8099` – unless you are doing some NATting or port forwarding there is usually no reason to change that. Port `8088` is an HTTP API by vMix that is not used by Wifi-Tally.

Amenasme, 2021-04-29:
Yeahh, now it works, I was using 8088 port too. With 8099 it works. Thank you! Maybe this thing must be written in the "getting started" section of the website to help people that don't know that.

I can't connect to atem mini too, I know the ip address of the atem mini but I don't know the port. Where can I read what port the atem mini is using? Thank you

tobiswdec, 2021-04-30:
closed, it fixed my issue

Closed 2021-04-30.

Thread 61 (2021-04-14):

no memory ESP

mnoscak, 2021-04-14:
Hi my ESP8266-12 4M after upload code (lua, lc)  (firmware: wifi-tally-v0.4.1)  says:

modules: encoder,file,gpio,net,node,pwm2,struct,tmr,uart,wifi,ws2812
 build 2021-03-07 10:38 powered by Lua 5.1.4 on SDK 3.0.1-dev(fce080e)
E:M 2155784
not enough memory
stack traceback:
	[C]: in function 'dofile'
	init.lua:1: in main chunk
	[C]: ?

Please why?     Thx Michal

czenker, 2021-04-20:
Hey Michal

That looks like a strange issue.

How much RAM can be used by the application? It is easy to find out if you remove `init.lua` from the ESP and reboot. `print(node.heap())` tells you how much RAM is free for use by the application. It should be a value around `40000`. For me it is `43520`. If it is significantly less, then it seems the firmware takes up to much space or your ESP has less memory than usual.

Do you remember where you bought the ESP? I would be interested to get one in my hands if it does not work.

czenker, 2021-05-15:
Closed for inactivity. Unclear how to reproduce.

Unyck, 2022-04-02:
I have the same issue, i check with the print(node.heap()) and my cheap have 42144 ram space, i got the exact same error than mnoscak the cheap come from Azdelivery its a nodeMcu V3

Closed 2021-05-15.

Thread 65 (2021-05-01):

uploading files to nodemcu

Amenasme, 2021-05-01:
Hi, i need some help to upload the file tally-setting.ini to the nodeMCU.
I am using ESPlorer and as you can see from the attached picture I got this error. I don't know the lua script, I just uploaded all the files and replace the ssid, password and ip on this file. Someone can help me? thank you
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

czenker, 2021-05-02:
Hey.

ESPlorer seems to *execute* `tally-settings.ini` as if it was LUA code. What you want to do is just move files around (ESPlorer can do sooooo much more than that) - **no** compiling or running needed. Also you need to rename `tally-settings.ini.example` to `tally-settings.ini` before uploading.

---

If you can't get it to work, you might give [NodeMCU-Tool](https://github.com/AndiDittrich/NodeMCU-Tool) a try too. I use that on Windows regularily and - personal taste - find it easier to use.

````bash
# install nodemcu-tool
> npm install nodemcu-tool -g

> nodemcu-tool devices
# the output looks similar to this:
#   [device]      ~ Device filter is active - only known NodeMCU devices (USB vendor-id) will be listed.
#   [device]      ~ Connected Devices | Total: 1
#   [device]      ~ - COM3 (Silicon Labs, USB\VID_10C4&PID_EA60\0001)

# Take note of the port of your connected device (COM3) in this example.
# You need to substitude it in all following commands

# then upload all the files
> cd Downloads\wifi-tally-v0.4.2\tally
> nodemcu-tool upload *.lc init.lua tally-settings.ini -p COM3

# and reboot (you might as well push the RST button or replug power)
> nodemcu-tool reset -p COM3
````

Amenasme, 2021-05-02:
I was not renaming `tally-settings.ini.example` to `tally-settings.ini`. Now it is working very good! thank you

Closed 2021-05-03.

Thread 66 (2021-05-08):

"On Air" sign for Vmix

Amenasme, 2021-05-08:
Hi, is it possible to use wifi-tally technology to switch an "on air" sign automatically when vmix is recording or streaming? I tried for example to put a transparent input on overlay 4, so it is always on air (but transparent, so not visible) and a tally connected to it. Then I programmed that when I start recording, it automatically goes on overlay 4. Is it possible to make this in a simpler way, and without using an overlay channel? Maybe this feature can interest other people?

Amenasme, 2021-05-12:
@czenker can I ask your opinion about this?

czenker, 2021-05-12:
Hey @Amenasme

Sure. 😄 I like the idea of having an "On Air" sign functionality. Buying one of those cheap light boxes and turning it into a "We are live" sign sounds like something I would love to do. 😉

I am just not sure what the best logic there is.

1. The easier version is to have a tally that shows the "on air" state if *any* channel of the mixer is "on air". I the dropdown could just show another option "any".
2. The flexibel version would be to allow multiple selections in the dropdown. But I am not sure if this is really needed.

Considering #63 is implemented, your use case would be solved with Option 1. Correct?

Option 2 would be better if you use lots of pre-recorded clips in vMix and your team could relax during that time. But this makes the UI more complex.

What are your preferences.

Amenasme, 2021-05-12:
I mean, the on air lights must be activated if recording or streaming in vmix are active, not connected to an input

Amenasme, 2021-05-12:
#63 I read this. If You can access to this data (vmix recording state and vmix streaming state) so maybe you can connect a tally to theese vmix states

Amenasme, 2021-05-12:
Someting like this, a sign that will switch on when vmix is recording or streaming

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

czenker, 2021-05-12:
> I mean, the on air lights must be activated if recording or streaming in vmix are active, not connected to an input

From the end-users perspective this should be the same, but it would be easier to implement this in a way that all other video mixers can profit as well.

I might need to look into it for vMix, but I don't expect there would be a (real world) situation, where you are streaming, but **no** input is active.

Did you build that Recording sign? It looks awesome. I need one of those, too. 😆

Amenasme, 2021-05-12:
Maybe I am streaming a pre-recorded video, or a powerpoint and in that case I want that all tally are off and recording/streaming sign is on.

On the other side, I can have camera 1 in program but I am not streaming or recording yet, in rehersal for example, so I want that tally works but recording7streaming sign is off.

That is a picture taken from internet but I built 2 on air sign controlled by nodeMCU with a domotic app (Blink for android) and I can chang the light status sending web request to the server of the app. It works but it is difficult to set up, and little weird to use with vmix. I work in a medium television studio that wants theese sign so when they saw on air sign is on, they can't open doors or make noise.  I don't have picture of my signs now but I can take photo the next time I go there

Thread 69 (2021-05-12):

allow to link video mixers

czenker, 2021-05-12:
Follow-up to #68:

With multiple mixers configured it should be possible to intelligently handle the "Program" state.

Consider a setup where all cameras run into a hardware mixer. An operator mixes the live video feed and the output is sent to a workstation running OBS which streams into the internet. At the moment a tally light on a camera would show up to be in "program", even if the output of the hardware mixer is not currently used in OBS or OBS is not streaming. When this issue is done the Tally should show up as "preview" in this case.

Amenasme, 2021-05-12:
So, if you have an ATEM mixer with camera connected to it, and the program goes to vmix, where you have remote calls, video, powerpoint etc, and assume you can connect ATEM and Vmix to the hub (in the same time, together), so you know when, for example camera 3 is on air in the atem but the tally will lights up only if input 1 in vmix (the program input from ATEM in vmix) is on air too. The hub must check which channel is on air in the Atem  AND  if the program input in vmix/obs is on air.

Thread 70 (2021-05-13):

What's the connection?

pwright2b, 2021-05-13:
I realize this is a really dumb question ... but what is the connection between the ATEM and the Hub?  I don't find any description or reference to it.  And I don't find any schematics on the BlackMagic site to help.

czenker, 2021-05-13:
Hi. There are no stupid questions.

I am not aware of any *official* documentation on the interface. It is an UDP event stream with binary data – so it is tricky to interpret. The interface is used officially by ATEM Software Control and has been [first reverse engineered and documented by SKAARHOJ](https://www.skaarhoj.com/discover/blackmagic-atem-switcher-protocol). This is also the only documentation of the interface I know of, but it is no longer maintained and might be outdated. We use [
tv-automation-atem-connection by NRK](https://github.com/nrkno/tv-automation-atem-connection) under the hood to communicate with ATEM. They have a working and maintained implementation, but – in their case – the source is the documentation.

pwright2b, 2021-05-13:
Well, but sometimes there are badly phrased ones.  I'm asking the really basic question of what kind of wire runs between the ATEM and the Hub.  USB?  9 Pin Serial?  VGA?

Thanks for the quick reply.

czenker, 2021-05-13:
Yeah – I got this one wrong. Still not a stupid question though :smile:

The answer is **ethernet**. There is a plug on the back labeled "Switcher Control" or "ATEM Control". Just connect that to a switch on your LAN and your LAN should give the ATEM Mixer an IP address. You might have to look the address up in your router, because I am not sure if your ATEM can show it to you. That is the IP you enter in the Hub. Just go with the default port and it should work.

For more details you can check out [this video on Youtube](https://youtu.be/7w3AGMPB83s?t=103) (this does not only work on ATEM Mini, but also Television Studio) or the section "Connecting to a Network" in the according handbooks.

And feel free to follow up if you need more detailed help.

pwright2b, 2021-05-14:
Fantastic.  Thank you for that.  And, yes, I may be back.  But I think I have enough to begin now.

Closed 2021-05-15.

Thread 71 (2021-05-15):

Me again.  How to install.

pwright2b, 2021-05-15:
OK.  Now I have an EeePC running Debian.  And I have downloaded the wifi-tally-v0.4.2.zip  and wifi-tally-v0.4.2.tar.gz.   But I have no idea how to/whether to install them.

----Paul-----

czenker, 2021-05-15:
Both of the archives contain the exact same files – so it does not matter which one you use. `tar.gz` is the format I would go with for linux, because any distribution can handle it without the need for additional packages. You just need to extract the archive using your file manager and should end up with a directory structure like that

````
wifi-tally-v0.4.2
  - documentation
  - firmware
  - hub
  - tally
````

You can ignore `firmware` and `tally` for now. You only need them when [building your own hardware](https://wifi-tally.github.io/getting-started/setup-wifi-tally.html). Open a terminal and enter the `hub` directory.

````bash
cd ~/Downloads/wifi-tally-v0.4.2/hub
````
(Your path might vary, depending where your stored it)

You might need to install nodejs, if you have not already:
````bash
sudo apt-get install nodejs
````

Then start the hub
````bash
npm run start
````

... and you can open a browser and should see the hub on http://127.0.0.1:3000

pwright2b, 2021-05-15:
Woo-hoo, it's  running.  Your instructions were great but I'm going to add a couple of things here because I expect some other noobs will find this thread useful.

Main guidance is:  when you get an error message, Google is your friend.

When I tried the sudo apt-get, I was informed I was not on the sudoers list.  Apparently a common fresh-install Debian issue.

Once I had nodejs installed and tried to run the hub, I was told npm was not a known command.  node -v worked but npm -v did not.  Again, apparently not all that uncommon.  A stackoverflow page gave me a curl command to run to fix it but then I had to install curl.

Finally , all seems to work.

Thank you.

-----Paul-----

pwright2b, 2021-05-23:
Aaand, I'm back.  Two pics attached from my present setup.  Which almost but not quite runs.
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

Asbestos I can tell, the wifi-tally and the hub are fully working.  They are all static IPs and connected by ethernet.  I have created one web tally on the hub and when I click 'Connect' I get a screen that turns colors depending on how Camera One is set.

My problem comes when trying to access from outside via wifi.  At first I attached a simple AP and tried to set up dhcp on the same machine as the hub.  Never could get configuration right.  All the config guides assume there will be an internet connection and trying to leave that out upsets them.

Finally I realized I had an AP that had its own dhcp server.  I now have that attached to the system.  It seems to work.  Some of my phone network utilities can see 10.55 and 10.240 within the network.  But I cannot find a way to log in to get the phone to acts as a wifi tallly.  I am sure I am missing something basic but hope that you can point it out to me.

I have to admit the 0.0.0.0:7411 notation has me stonkered.

-----Paul-----

czenker, 2021-05-24:
Hey.

Great you made it this far.

> Asbestos I can tell, the wifi-tally and the hub are fully working.

Yes. Connection from Hub to ATEM looks perfect. :+1:

> I have to admit the 0.0.0.0:7411 notation has me stonkered.

This address will not help you much. `0.0.0.0` is a special IP address that basically means that connections on all your network devices are accepted. So if your EeePC was connected via wire and wifi you could connect to the hub with either IP address. `7411` is the port.

To get the IP address of your EeePC, type `ip addr`. It returns something like this:

````plain
1: lo: <LOOPBACK,UP,LOWER_UP> mtu 65536 qdisc noqueue state UNKNOWN group default qlen 1000
    link/loopback 00:00:00:00:00:00 brd 00:00:00:00:00:00
    inet 127.0.0.1/8 scope host lo
       valid_lft forever preferred_lft forever
    inet6 ::1/128 scope host
       valid_lft forever preferred_lft forever
2: enp4s0: <BROADCAST,MULTICAST,UP,LOWER_UP> mtu 1500 qdisc pfifo_fast state UP group default qlen 1000
...
    inet 192.168.178.42/24 brd 192.168.178.255 scope global dynamic noprefixroute enp4s0
       valid_lft 861173sec preferred_lft 861173sec
    inet6 fe80::6fb5:452e:c846:5c10/64 scope link noprefixroute
       valid_lft forever preferred_lft forever
3: virbr0: <NO-CARRIER,BROADCAST,MULTICAST,UP> mtu 1500 qdisc noqueue state DOWN group default qlen 1000
    link/ether 52:54:00:28:27:7d brd ff:ff:ff:ff:ff:ff
    inet 192.168.122.1/24 brd 192.168.122.255 scope global virbr0
       valid_lft forever preferred_lft forever
...
````

Look for the address starting with `192.168.10` – that is the address you want your smartphones to connect to. In my example this address is `192.168.178.42`. So I type `http://192.68.178.42:3000` in my browser.

> My problem comes when trying to access from outside via wifi.

Configuring networks can be quite confusing when doing it for the first time. It's a good decision to **not** run your own DHCP server. Speaking from experience. :smile:

I understand your network layout looks similar to this!?

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

The point where you seem to have trouble is the connection between your AP and the (old) router, correct? Did you manage to connect *any* devices that are on the different networks?

The AP seems to give out IP Addresses like `10.55.*.*` or `10.240.*.*`, but your ATEM has the address `192.168.10.240`. Did you configure the **routing tables** to connect those two networks?

How you do this is highly depended on the devices you use. What you basically need to achieve is to tell your AP "if you get packages for an IP address that matches the pattern `192.168.178.*`, send it to the router instead". And your Router needs to know "if you get packages for an IP address that matches `10.55.*.*` or `10.240.*.*`, send it to the access point".

I hope this helps you further and the information was not too basic or high-level. **Routing table** and the name of your AP or router is what you might want to search for.

If it does not help, feel free to check back.

pwright2b, 2021-05-24:
Routing Tables, oh dear.  I have never ventured that deep into the jungle before.  But if that is what I need, I shall venture forth.  I do appreciate your guidance.  Yes, you visualize the network layout properly.   The router is a Netgear unmanaged switch, so as far as I can tell it doesn't change anything passing thru it.   I appreciate your confirming that the address I am trying to reach is  http://192.168.10.55:3000.  I believe I have the access point configured to give out 192.168.10.x addresses but I will do what I can to double check that.

-----Paul-----

pwright2b, 2021-05-24:
OK, I thrashed around a good bit today.  Made enough changes to the router setup that I feared I would never get it going again.  Network configuration is truly a blend of witchcraft and black magic.  Anyhow, in the end it seems that my technology has been fooling me and it has been working all the time.  At any rate I can log in via wifi to 198.164.10.55:3000 using a laptop browser and the remote Tally function works just fine.   But, for the life of me I cannot get a phone based browser to successfully log in.  I have tried an android and an iPhone (old).  They both attach to the network and accept the URL and appear to begin to load the page but then stop, with nothing rendered.  No error codes, just stop.
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
pwright2b, 2021-06-01:
**IT WORKS!!**  First I decided to guess that the reference to Common Cathode might mean some discrete LEDs with the cathodes tied together.  Then I had to look up how to determine which was the cathode.  Then I spent an hour fruitlessly testing.  Then I reread the instructions and finally noticed that it said to connect to GND rather than 3v3.  And then I tested some different connection points and finally got an LED to turn on ... and off.  And then another LED at a different connection point turned on and off.  And now it tells me whether the camera is on preview or live.

Whahoo!  Thank you.  This is great.  Now if I can just package it in a moderately attractive package ....

*****Not your problem. *****

But maybe you could add a few more explanatory words to the section about Common Cathode.   1.  That it refers (or can refer) to discrete LEDs, and 2.  That they will use the same pins (D1, D2, D3) as the Build and Setup a Wifi Tally page EXCEPT using GND instead of 3v3.

-----Paul-----

czenker, 2021-06-01:
Awesome!

It's always tricky to get documentation right to cater different audiences, but you are right there could be more details or an example schematic on your setup. Feel free to create a pull request on the documentation with the information that might have helped you. In the future I hope to have guides for different setups – with one recommended setup.

Just one thing to add: Did you add any resistors to the LEDs? When using discrete LEDs you should always add a resistor between the pin D1, D2, D3 and the respective pins on the LED. Otherwise you might risk burning the LED. It usually does not happen quickly, but reliability is key for a tally light. :wink: `150Ohm` for red and `100Ohm` for blue and green are common values to use.

czenker, 2021-06-02:
> Does the value for operator.ws2812 need any adjustment?

No. If you don't use it, it does not matter what you set. You could set it to `0`, but you would not see any performance difference anyways.

pwright2b, 2021-06-07:
Your comment on 'create a pull request' reminded me how little I know about the github environment. And then I got a note about renaming to vtally.  So I looked around in history.

.... My god you have poured a lot of work into this.  And I am so grateful for your support.

So far I have built a Mk 1 [(cardboard box size of an old cigarette case), ugly as home made sin but works], Mk 1 Mod 1 (smaller plastic case), and  a MK 2 model where the lights are on a cord independent of the case.  Trying to build a second Mk 2 but my clumsy fingers are in the way.

So far have not succeeded in incorporating WS2812, only individual LEDs, but they work fine and serve our purpose.

I don't want to violate githubs standards but would be interested in trying the 'pull request' and adding some commentary.  Is there a style guide or whatever I should peruse?

----Paul------

czenker, 2021-06-13:
> I don't want to violate githubs standards but would be interested in trying the 'pull request' and adding some commentary.

There is not much to worry about. 😄 Everyone of started with their first pull request at some point. The good thing is: You can't really break anything. So don't panic. I can have a look before your changes are integrated.

> Is there a style guide or whatever I should peruse?

There is not really a styleguide. The documentation is generated by some files in the [documentation](https://github.com/wifi-tally/wifi-tally/tree/main/documentation/docs) directory. The file format is markdown (the same markup language you can use in the github comments) plus a few plugins for variable substitution and info boxes. You can edit it with any text editor or even with the browser editor on Github. The syntax should be pretty obvious, if you compare the markdown files with the rendered documentation.

If you want to see your result before submitting to github this should be really easy on a linux machine (you are working on the Eee Pc, right?). [Brief documentation is here](https://github.com/wifi-tally/wifi-tally/blob/main/documentation/Readme.md), but this should work for you on Debian:

````bash
# this should be installed by default, but to be sure
sudo apt-get install python3

cd documentation/
python3 -m pip install -r requirements.txt --user

mkdocs serve
````

and open your browser on http://127.0.0.1:8000 It should update the documentation shown everytime you save your changes.

czenker, 2021-12-28:
Discussion went stale. Closing.

Closed 2021-12-28.

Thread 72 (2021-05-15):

Help Needed: Test v0.5.0 before official release

czenker, 2021-05-15:
Hey everyone.

I'm almost ready to publish the next big release. But as the way of installation has changed (hopefully to be even easier now), I want **as many people as possible to test it on their hardware** to iron out any incosistencies or bugs that might come up.

The new release includes multiple changes that I am really exited about:

1. We have a logo. And a new name :tada:
    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
2. @JWandscheer added support for Roland VR-50HD and V-8HD :clap:
3. It is now possible to modify `tally-settings.ini` and update the code from the Hub via USB.

The latter two changes also required the change in the installation procedure.

So please give it a try. I post the new installation instruction right here as the first comment. If it works for you or you run into issues, please use this issue to report.

----

**It is no longer necessary to install nodeJS.** It is bundled with the releases now.

## Windows

Download and run: https://wifi-tally-nightly.s3.eu-central-1.amazonaws.com/vtally-0.5.0-alpha2-win-portable.exe

You will have to klick away a bunch of security messages by Windows defender and convince Windows you *really* trust this binary

It will show a tray icon once it is started. Point your Browser to http://localhost:8000 and you should see the Hub. To stop the process, right click the tray icon and select `Exit`.

## Linux

Download and run: https://wifi-tally-nightly.s3.eu-central-1.amazonaws.com/vtally-0.5.0-alpha2-linux-x86_64.AppImage

````bash
wget -O vtally-0.5.0-alpha2-linux-x86_64.AppImage https://wifi-tally-nightly.s3.eu-central-1.amazonaws.com/vtally-0.5.0-alpha2-linux-x86_64.AppImage
chmod a+x vtally-0.5.0-alpha2-linux-x86_64.AppImage
./vtally-0.5.0-alpha2-linux-x86_64.AppImage
````

## MacOSX

I don't have any MacOS at hand, so this guide is just a rough shot and you might need to work around a few issues. Please report your findings so they can be fixed or documented.

Download and run https://wifi-tally-nightly.s3.eu-central-1.amazonaws.com/vtally-0.5.0-alpha2-mac.dmg

You might have to klick away a bunch of security messages and convince Mac you *really* trust this binary

It should show a tray icon once it is started. Point your Browser to http://localhost:8000 and you should see the Hub. To stop the process, right click the tray icon and select `Exit`.

Amenasme, 2021-05-16:
I will try... seems very difficult for not a programmer (me).
Where do I have to insert all these codes?

czenker, 2021-05-20:
> Where do I have to insert all these codes?

You run on Windows, right?

Just open the command line (windows + type "cmd" + enter). Don't fear the command line – it's friendly most of the time. :laughing:

Amenasme, 2021-05-26:
I tried and I stopped with errors at the beginning. I can't do that, it's too difficult for me.  Can you do a step by step video of the installation process? Maybe in the future a  *.exe  file will help people like me (not a programmer).

czenker, 2021-05-29:
> I tried and I stopped with errors at the beginning. I can't do that, it's too difficult for me. Can you do a step by step video of the installation process? Maybe in the future a *.exe file will help people like me (not a programmer).

I uploaded a video how the initial installation should ideally look like on Windows: https://vimeo.com/556543349

Where exactly do the errors occur? What do the errors say?

Amenasme, 2021-06-01:
Thanks for the video, it is useful but I got this error anyway. I installed node.js as in your video. What I have to do?
Thanks

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

Amenasme, 2021-06-01:
I have a 64bit windows OS

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

czenker, 2021-06-01:
> Thanks for the video, it is useful but I got this error anyway. I installed node.js as in your video. What I have to do?
> Thanks

Hey.

I guess you have downloaded the 32bit node installer by accident. Remove it and install the 64bit version. The latest current version is https://nodejs.org/dist/v14.17.0/node-v14.17.0-x64.msi

Then try again.

Amenasme, 2021-06-01:
> I guess you have downloaded the 32bit node installer by accident

Yes, I did. I don't know why, and I didn't noticed it.

Now I removed it and installed the version that you linked to me. I ran cmd and wrote:

npm install -g vtally@0.5.0-alpha2

and got all these errors

`
C:\Users\Salvatore>npm install -g vtally@0.5.0-alpha2
npm WARN tar ENOENT: no such file or directory, open 'C:\Users\Salvatore\AppData\Roaming\npm\node_modules\.staging\es-abstract-71d0f476\2016\CreateDataProperty.js'
npm WARN tar ENOENT: no such file or directory, open 'C:\Users\Salvatore\AppData\Roaming\npm\node_modules\.staging\es-abstract-71d0f476\2017\CreateDataProperty.js'
npm WARN tar ENOENT: no such file or directory, open 'C:\Users\Salvatore\AppData\Roaming\npm\node_modules\.staging\es-abstract-71d0f476\2018\CreateDataProperty.js'
npm WARN tar ENOENT: no such file or directory, lstat 'C:\Users\Salvatore\AppData\Roaming\npm\node_modules\.staging\vtally-f2aa0d13\src\frontend\static'
npm WARN tar ENOENT: no such file or directory, open 'C:\Users\Salvatore\AppData\Roaming\npm\node_modules\.staging\atem-connection-3fd4e63b\dist\commands\TallyBySourceCommand.d.ts'
npm WARN tar ENOENT: no such file or directory, open 'C:\Users\Salvatore\AppData\Roaming\npm\node_modules\.staging\es-abstract-71d0f476\2016\CreateDataPropertyOrThrow.js'
npm WARN tar ENOENT: no such file or directory, open 'C:\Users\Salvatore\AppData\Roaming\npm\node_modules\.staging\atem-connection-3fd4e63b\dist\commands\TallyBySourceCommand.js'
npm WARN tar ENOENT: no such file or directory, open 'C:\Users\Salvatore\AppData\Roaming\npm\node_modules\.staging\es-abstract-71d0f476\2017\CreateDataPropertyOrThrow.js'
npm WARN tar ENOENT: no such file or directory, open 'C:\Users\Salvatore\AppData\Roaming\npm\node_modules\.staging\atem-connection-3fd4e63b\dist\commands\TallyBySourceCommand.js.map'
npm WARN tar ENOENT: no such file or directory, open 'C:\Users\Salvatore\AppData\Roaming\npm\node_modules\.staging\es-abstract-71d0f476\2018\CreateDataPropertyOrThrow.js'
npm WARN tar ENOENT: no such file or directory, open 'C:\Users\Salvatore\AppData\Roaming\npm\node_modules\.staging\atem-connection-3fd4e63b\dist\commands\TimeCommand.d.ts'
npm WARN tar ENOENT: no such file or directory, open 'C:\Users\Salvatore\AppData\Roaming\npm\node_modules\.staging\atem-connection-3fd4e63b\dist\commands\TimeCommand.js'
npm WARN tar ENOENT: no such file or directory, open 'C:\Users\Salvatore\AppData\Roaming\npm\node_modules\.staging\atem-connection-3fd4e63b\dist\commands\TimeCommand.js.map'
npm WARN tar ENOENT: no such file or directory, open 'C:\Users\Salvatore\AppData\Roaming\npm\node_modules\.staging\atem-connection-3fd4e63b\dist\commands\index.d.ts'
npm WARN tar ENOENT: no such file or directory, open 'C:\Users\Salvatore\AppData\Roaming\npm\node_modules\.staging\es-abstract-71d0f476\2016\CreateHTML.js'
npm WARN tar ENOENT: no such file or directory, open 'C:\Users\Salvatore\AppData\Roaming\npm\node_modules\.staging\atem-connection-3fd4e63b\dist\commands\index.js'
npm WARN tar ENOENT: no such file or directory, open 'C:\Users\Salvatore\AppData\Roaming\npm\node_modules\.staging\es-abstract-71d0f476\2017\CreateHTML.js'
npm WARN tar ENOENT: no such file or directory, open 'C:\Users\Salvatore\AppData\Roaming\npm\node_modules\.staging\atem-connection-3fd4e63b\dist\commands\index.js.map'
npm WARN tar ENOENT: no such file or directory, open 'C:\Users\Salvatore\AppData\Roaming\npm\node_modules\.staging\es-abstract-71d0f476\2018\CreateHTML.js'
npm WARN tar ENOENT: no such file or directory, open 'C:\Users\Salvatore\AppData\Roaming\npm\node_modules\.staging\midi-a3c0c2cc\test\input\virtual-input-test.js'
npm WARN tar ENOENT: no such file or directory, open 'C:\Users\Salvatore\AppData\Roaming\npm\node_modules\.staging\atem-connection-3fd4e63b\dist\dataTransfer\dataLock.d.ts'
npm WARN tar ENOENT: no such file or directory, open 'C:\Users\Salvatore\AppData\Roaming\npm\node_modules\.staging\atem-connection-3fd4e63b\dist\dataTransfer\dataLock.js'
npm WARN tar ENOENT: no such file or directory, open 'C:\Users\Salvatore\AppData\Roaming\npm\node_modules\.staging\atem-connection-3fd4e63b\dist\dataTransfer\dataLock.js.map'
npm WARN tar ENOENT: no such file or directory, open 'C:\Users\Salvatore\AppData\Roaming\npm\node_modules\.staging\es-abstract-71d0f476\2016\CreateIterResultObject.js'
npm WARN tar ENOENT: no such file or directory, open 'C:\Users\Salvatore\AppData\Roaming\npm\node_modules\.staging\atem-connection-3fd4e63b\dist\dataTransfer\dataTransfer.d.ts'
npm WARN tar ENOENT: no such file or directory, open 'C:\Users\Salvatore\AppData\Roaming\npm\node_modules\.staging\es-abstract-71d0f476\2017\CreateIterResultObject.js'
npm WARN tar ENOENT: no such file or directory, open 'C:\Users\Salvatore\AppData\Roaming\npm\node_modules\.staging\atem-connection-3fd4e63b\dist\dataTransfer\dataTransfer.js'
npm WARN tar ENOENT: no such file or directory, open 'C:\Users\Salvatore\AppData\Roaming\npm\node_modules\.staging\es-abstract-71d0f476\2018\CreateIterResultObject.js'
npm WARN tar ENOENT: no such file or directory, open 'C:\Users\Salvatore\AppData\Roaming\npm\node_modules\.staging\atem-connection-3fd4e63b\dist\dataTransfer\dataTransfer.js.map'
npm WARN tar ENOENT: no such file or directory, open 'C:\Users\Salvatore\AppData\Roaming\npm\node_modules\.staging\atem-connection-3fd4e63b\dist\dataTransfer\dataTransferAudio.d.ts'
npm WARN tar ENOENT: no such file or directory, open 'C:\Users\Salvatore\AppData\Roaming\npm\node_modules\.staging\atem-connection-3fd4e63b\dist\dataTransfer\dataTransferAudio.js'
npm WARN tar ENOENT: no such file or directory, open 'C:\Users\Salvatore\AppData\Roaming\npm\node_modules\.staging\atem-connection-3fd4e63b\dist\dataTransfer\dataTransferAudio.js.map'
npm WARN tar ENOENT: no such file or directory, open 'C:\Users\Salvatore\AppData\Roaming\npm\node_modules\.staging\atem-connection-3fd4e63b\dist\dataTransfer\dataTransferClip.d.ts'
npm WARN tar ENOENT: no such file or directory, open 'C:\Users\Salvatore\AppData\Roaming\npm\node_modules\.staging\es-abstract-71d0f476\2016\CreateListFromArrayLike.js'
npm WARN tar ENOENT: no such file or directory, open 'C:\Users\Salvatore\AppData\Roaming\npm\node_modules\.staging\atem-connection-3fd4e63b\dist\dataTransfer\dataTransferClip.js'
npm WARN tar ENOENT: no such file or directory, open 'C:\Users\Salvatore\AppData\Roaming\npm\node_modules\.staging\es-abstract-71d0f476\2017\CreateListFromArrayLike.js'
npm WARN tar ENOENT: no such file or directory, open 'C:\Users\Salvatore\AppData\Roaming\npm\node_modules\.staging\atem-connection-3fd4e63b\dist\dataTransfer\dataTransferClip.js.map'
npm WARN tar ENOENT: no such file or directory, open 'C:\Users\Salvatore\AppData\Roaming\npm\node_modules\.staging\es-abstract-71d0f476\2018\CreateListFromArrayLike.js'
npm WARN tar ENOENT: no such file or directory, open 'C:\Users\Salvatore\AppData\Roaming\npm\node_modules\.staging\atem-connection-3fd4e63b\dist\dataTransfer\dataTransferFrame.d.ts'
npm WARN tar ENOENT: no such file or directory, open 'C:\Users\Salvatore\AppData\Roaming\npm\node_modules\.staging\atem-connection-3fd4e63b\dist\dataTransfer\dataTransferFrame.js'
npm WARN tar ENOENT: no such file or directory, open 'C:\Users\Salvatore\AppData\Roaming\npm\node_modules\.staging\atem-connection-3fd4e63b\dist\dataTransfer\dataTransferFrame.js.map'
npm WARN tar ENOENT: no such file or directory, open 'C:\Users\Salvatore\AppData\Roaming\npm\node_modules\.staging\es-abstract-71d0f476\2016\CreateMethodProperty.js'
npm WARN tar ENOENT: no such file or directory, open 'C:\Users\Salvatore\AppData\Roaming\npm\node_modules\.staging\atem-connection-3fd4e63b\dist\dataTransfer\dataTransferStill.d.ts'
npm WARN tar ENOENT: no such file or directory, open 'C:\Users\Salvatore\AppData\Roaming\npm\node_modules\.staging\es-abstract-71d0f476\2017\CreateMethodProperty.js'
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

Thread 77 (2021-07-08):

Increase maximum number of ws2812 leds to at least 30

AndreBott83, 2021-07-08:
Could you change the my-settings.lua file to support higher numbers of ws2812 leds for Operator and Stage lights?
E.g. increase the input checks to 30

czenker, 2021-12-29:
Sorry for the late response.

What is the use case here?

Limiting the number of LEDs is mostly done for two reasons:

* Writing data for WS2812 takes time. The more LEDs you have, the longer it takes, which might lead to laggy output. I'm not sure about the NodeMCU-internals, but the `wifi` and `ws2812` module should both work with interrupts. Just from experience I think it is better to reduce the workload inside interrups as much as possible. Otherwise this could cause dropped UDP packages or flickering LEDs
* NodeMCU boards have a limit to total current drain of about `250mA`. Having too many LEDs connected might potentially damage the board.

If there is a need for an "expert option" to support more LEDS, there might be some way to support it. But you should know what you are doing and can not just follow the documentation.

AndreBott83, 2021-12-30:
Hi,
don't worry about the delayed response and thx for the extensive answer.

The use case was to make use of  WS2812 LED rings as a tally signal. E.g. the NeoPixel ring (https://www.amazon.de/gp/aw/d/B01B35DDTU)
The 24 LEDs are permanently attached and it looks a lot nicer if all of the leds are on.

The power supply is directly supplied to the soldering terminals and not taken through the NodeMCU board outputs to not toast the internals or  trip a fuse.

Latency and connection looks fine. I did also not notice a flickering of the leds with the number set to 24+2 in my test.

But I agree, maybe that extension should be behind some expert Modus to be on the safe side

sinnoken, 2024-10-10:
Can it be increased to 64, for example using 8x8 RGB Shield？
https://www.wemos.cc/en/latest/d1_mini_shield/8x8_rgb.html

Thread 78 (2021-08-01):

Problem with Atem connection

IbroZe, 2021-08-01:
Hello,
version 0.5.0 tally hub for windows cannot be connected to Atem mixer.  I tried from another computer but without success.  Version 0.3.0 connects to atem mini pro and atem production studio without any problems.
Best regards.

sisensee, 2021-08-22:
I can confirm same problem for a Mac. Two Macs, two OS versions, tally's connect and update code accordingly, but no connection to ATEM.

Numelle, 2021-11-01:
Same Problem here. Scenarios tested:
Scenario 1:
- ATEM Mini Pro
- Mac (Intel) BigSur  11.6 (normal firewall configuration - no special changes)
- vTally Hub 0.5.0
- 1 Tally connected
- Port 9910 from HUB Device to ATEM Mini Pro verified and open
- No other network connections to ATEM than the vTally Hub
Result:
NO Connection established
Scenario 2:
- ATEM Mini Pro
- Mac (Intel) BigSur  11.6 fresh installation without AV or FW tooling
- vTally Hub 0.5.0
- 1 Tally connected
- Port 9910 from HUB Device to ATEM Mini Pro verified and open
- No other network connections to ATEM than the vTally Hub
- Clean separate network on a dedicated router.
Result:
NO Connection established
Hope this helps solving the issue for 0.5.0.
Thanks! ;-)

Numelle, 2021-11-09:
Hey @czenker @kubikrubik21  I was wondering if there is an update to this issue?
Are there any others who have this issue with current version and want to connect with ATEM?
Is there any additional information needed from my side?
Thank you very much ;-)

czenker, 2021-11-13:
Finally got around to getting some logs

````
[2021-11-13 15:17:16.309] [error] (node:10256) UnhandledPromiseRejectionWarning: Timeout when trying to restart
[2021-11-13 15:17:16.310] [error] (node:10256) UnhandledPromiseRejectionWarning: Unhandled promise rejection. This error originated either by throwing inside of an async function without a catch block, or by rejecting a promise which was not handled with .catch(). To terminate the node process on unhandled promise rejection, use the CLI flag `--unhandled-rejections=strict` (see https://nodejs.org/api/cli.html#cli_unhandled_rejections_mode). (rejection id: 5691)
[2021-11-13 15:17:16.345] [error] (node:10256) UnhandledPromiseRejectionWarning: Timeout when trying to restart
[2021-11-13 15:17:16.345] [error] (node:10256) UnhandledPromiseRejectionWarning: Unhandled promise rejection. This error originated either by throwing inside of an async function without a catch block, or by rejecting a promise which was not handled with .catch(). To terminate the node process on unhandled promise rejection, use the CLI flag `--unhandled-rejections=strict` (see https://nodejs.org/api/cli.html#cli_unhandled_rejections_mode). (rejection id: 5692)
[2021-11-13 15:17:16.357] [error] (node:10256) UnhandledPromiseRejectionWarning: Timeout when trying to restart
[2021-11-13 15:17:16.357] [error] (node:10256) UnhandledPromiseRejectionWarning: Unhandled promise rejection. This error originated either by throwing inside of an async function without a catch block, or by rejecting a promise which was not handled with .catch(). To terminate the node process on unhandled promise rejection, use the CLI flag `--unhandled-rejections=strict` (see https://nodejs.org/api/cli.html#cli_unhandled_rejections_mode). (rejection id: 5693)
[2021-11-13 15:17:16.362] [error] Worker Thread error Error: Cannot find module 'C:\Users\shark\AppData\Local\Temp\20rnAXhmnuYhkEx6FPpDWyUy8uD\resources\app.asar\node_modules\threadedclass\dist\child-process\threadedclass-worker.js'
    at Function.Module._resolveFilename (internal/modules/cjs/loader.js:887:15)
    at Function.Module._load (internal/modules/cjs/loader.js:732:27)
    at Function.executeUserEntryPoint [as runMain] (internal/modules/run_main.js:72:12)
    at MessagePort.<anonymous> (internal/main/worker_thread.js:174:24)
    at MessagePort.[nodejs.internal.kHybridDispatch] (internal/event_target.js:354:41)
    at MessagePort.exports.emitMessage (internal/per_context/messageport.js:18:26)
````
This is obviously something [atem-connection](https://www.npmjs.com/package/atem-connection) internal, that does not like to run inside electron. Unfortunately I do not expect there to be a quick solution.

For now the best way of action would be to [install vTally from npm](https://wifi-tally.github.io/download.html#run-from-npm). You miss the tray icon, but it works with Atem.

czenker, 2021-12-28:
The issue is mentioned in https://github.com/nrkno/tv-automation-atem-connection/issues/106 Updating atem-connection to version 3+ could help.

Numelle, 2021-12-28:
Hi there,

thanks for your efforts, but to be really honest I do not know which part to update

to fix the issue.

With regards to the MAC package could you give me a quick hint how to start?

Or is there a plan to do an update in the package accordingly?

Thanks

Andreas

Von: Christian Zenker ***@***.***>
Antworten an: wifi-tally/wifi-tally ***@***.***>
Datum: Dienstag, 28. Dezember 2021 um 11:23
An: wifi-tally/wifi-tally ***@***.***>
Cc: Numelle ***@***.***>, Comment ***@***.***>
Betreff: Re: [wifi-tally/wifi-tally] Problem with Atem connection (#78)

The issue is mentioned in nrkno/tv-automation-atem-connection#106 Updating atem-connection to version 3+ could help.

—
Reply to this email directly, view it on GitHub, or unsubscribe.
Triage notifications on the go with GitHub Mobile for iOS or Android.
You are receiving this because you commented.Message ID: ***@***.***>

czenker, 2021-12-28:
Sorry for closing this issue too early. I just released a new build [v0.5.1-rc1](https://github.com/wifi-tally/wifi-tally/releases/tag/0.5.1-rc1). This seems to fix the issue for me. Does it work for you, too, @Numelle? If so, I would do a proper release.

Numelle, 2021-12-28:
Hi Christian, will test that accordingly. Thanks for that. You will get asap Feedback.

czenker, 2022-01-21:
This should be fixed with [v0.5.1](https://github.com/wifi-tally/wifi-tally/releases/tag/0.5.1).

Closed 2022-01-21.

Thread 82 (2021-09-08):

Support DeviceWell HDS7105 with RS232

sinnoken, 2021-09-08:
Is it possible to integrate with DeviceWell HDS7105? Using RS232 Direct connection.

https://www.videodata.de/shop/media/products/DeviceWell_HDS7105_Manual.pdf

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

czenker, 2021-11-13:
Hey @sinnoken.  Welcome to the project.

Theoretical it would be possible, I guess. But in reality someone with access to the requested device needs to implement it.

Personally I would not use the Pin-Interface, as this is intended to directly power the tally lights. You would need to run that signal into the computer that runs the Hub. This would require some sort of RS232->USB converter. And - according to the spec - you would need to add some pull-up resistors, as the pins are not connected when tally is off. That approach sounds a bit too fragile to me.

But there is a network interface and an official way to run this mixer remote. That's the way I think is easier to interface with. But this heavily depends if the protocol is specified or simple enough to be implemented in vTally.

I will leave this issue open. Please react with a 👍 if you are also interested in this feature. Maybe someone wants to implement support for this device.

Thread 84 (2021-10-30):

Lights off when video mixer disconnected

wde, 2021-10-30:
Hi there, I love this project! When using OBS (haven't tested with ATEM yet) and we shut down OBS the last known status remains and then if we close vTally Hub the units default to the double-flash blue connection warning.

We are putting these onto PTZ cameras that also double as security cameras when the ATEM is off.

Is there a way to get the LEDs to sleep when either the hub or ATEM is not connected?

I get that there needs to be a signal that the tally light is ready, maybe after 10 minutes or so it can switch to a tiny dim flicker every 20 seconds or so. Mostly in order to avoid it distracting people in the theatre. Or even a fade in/out dimly.

Many thanks for a great idea.
Cheers,
Sean

czenker, 2021-11-13:
Hey and welcome, Sean.

> we shut down OBS the last known status remains and then if we close vTally Hub the units default to the double-flash blue connection warning.

That sounds like a bug. It should start flashing with some pattern when OBS disconnects. But I understand that is not your main concern. 😄

> Is there a way to get the LEDs to sleep when either the hub or ATEM is not connected?

I guess, you are operating your cameras remote then? So I guess, you would not need a dedicated light for the operator. How about you only connect the Stage Lights, but not the Operator Lights? ([documentation here](https://wifi-tally.github.io/getting-started/setup-wifi-tally.html#separate-operator-and-stage-light)) The Stage Light never shows _any_ status other the `Preview` and `Program`. When using WS2812B strips, it should be possible to set this to have the same effect:

````ini
operator.ws2812 = 0
````

This would prevent the tally from ever flashing blue.

Does this help?
Christian.

wde, 2021-11-23:
Thanks Christian, That is a great idea. I am using WS2812Bs.

I might have a look at the code and play with it locally. If I come up with any brilliant ideas I'll submit them. Still love the project as broadcasting becomes more ubiquitous most of us can't afford a $6,000 tally system like the TV studios of the "olden days".

Cheers,
Sean

Closed 2021-11-23.

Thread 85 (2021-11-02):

vMix Channels

zuperzuche, 2021-11-02:
Before building wifi modules I decided to test web tallies with vMix. As far as I understand only 8 channels are supported and they correspond to inputs 1-8. I was wondering if it is possible to have more channels?

czenker, 2021-11-13:
Hey @zuperzuche and welcome.

If you select vMix as your video mixer and the connection is successful, vTally Hub should show the correct number of channels and their channel names. If not, let me know - this would be a bug.

The 8 channels is just a default if no video mixer is selected yet.

MartLeib, 2022-01-20:
It seems that I have a similar issue, If I select vMix and enter vMix Web Interface IP and port, then it connects to vMix for a second or sometimes longer, but never shows input names, only Unpatched and Channels 1-8.

Log is attached.
[main.log](https://github.com/wifi-tally/wifi-tally/files/7903895/main.log)
.

czenker, 2022-01-21:
Hey @MartLeib.

Thanks for adding the log. This really helped figuring out what's wrong: It is the port. It needs to be port `8099` of the [TCP API](https://www.vmix.com/help24/index.htm?TCPAPI.html), *not* the web UI.

If this fixes the issue, I would leave this ticket open and change its title, because the log should not say, it is connected to the mixer as this is obviously not the case.

MartLeib, 2022-01-22:
Hei @czenker when I changed 8088 to 8099 it worked right away. No need to restart or anything.
I would recommend not showing port selection for vMix at all because the port 8099 for TCP API is fixed and users can not change it. Users can change only the Web Controller port.

czenker, 2022-02-03:
There are some – admittedly rare – cases where the port might be changed when doing some network magic. So i would rather keep this logic in. I hope that the warning and logs added in the commits above will prevent users from changing the port unintentionally.

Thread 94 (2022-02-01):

Увеличение функционала. Поддержка батареи, LILYGO® TTGO T-OI ESP8266 / LILYGO®TTGO T-OI PLUS RISC-V MCU

DJAlexNed, 2022-02-01:
Добавьте пожалуйста поддержку одной из этих плат. Данная плата имеет аккумулятор и устройство зарядки, на пине A0 уже подключена батарея для мониторинга уровня заряда, так же на любом из ESP через делитель напряжения можно контролировать уровень заряда батареи. Добавив код уровня заряда можно сделать индикацию состояния для оператора с отправкой данных на хаб. что положительно скажется на размерах итогового устройства

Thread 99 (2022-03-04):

Multiple sources.

mndmr, 2022-03-04:
I have two sources in which a  camera is on. Is it possible to patch to multiple sources?

Furchendackel, 2023-04-25:
+1

Sometimes you have multiple scenes in OBS where the same camera is active (split screen or PiP). Would be great and useful for such circumstances.

czenker, 2023-04-27:
Hey @Furchendackel

> Sometimes you have multiple scenes in OBS where the same camera is active (split screen or PiP). Would be great and useful for such circumstances.

This is already possible with OBS. Create a scene that just contains your camera image full screen. You can use this scene as source in a different scene for PiP or split screens. Configure your tally to track the full screen scene and it should also activate anywhere this scene is embedded into a different scene. I have not tested it in the last year, but it worked in the past.

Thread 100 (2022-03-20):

Manual mixer input?

ben-bole, 2022-03-20:
Hey there,
I am currently preparing for a charity concert livestream, where I need at least one tally. Because I am using a rather uncommon video mixer (RGBlink mini+), which is not compatible with the common tally light software products, I am in need of an manual alternative. A script or just basic web interface trigger, to set the respective tally light to "on-air" or "preview".
Is there something you can recommend me?
Thanks in advance, Benedict

Closed 2022-03-21.

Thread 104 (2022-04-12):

RTLduino support

matiaspl, 2022-04-12:
2.4G wifi tends to fail on large events (I've seen it too many times), all technical crews tend to use 5G for that reason. It would be really great to have a tally system ported to an IOT device that supports 5G wifi out of the box.

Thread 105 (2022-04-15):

add battery status

davide92br, 2022-04-15:
I'm building a tally with wemos d1 mini with integrated battery and it would be nice to include a function that checks the battery status from the web server so that I can monitor the charge level.

GwiezdnySzeryf, 2022-05-24:
It would indeed be great function to have!

czenker, 2022-05-24:
Sounds like a great idea. I am just not sure how this would technically work. With some "stupid" battery the best you could do is monitor the voltage and guess how much capacity is left. But with all the different batteries and chips out there, this seems to be closer to reading tea leaves.

Does anyone have practical experience how to implement this savely? Or any implementation in a similar project?

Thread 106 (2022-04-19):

color connection

EnoqueCardosoNeves, 2022-04-19:
Hello, is it possible to change the connection color code, when it is connected to the server, when it is connected.
I say this because what you have right now is all blue.
Thanks

czenker, 2022-05-01:
Hi

This sounds a bit odd. It should be a dim green when the tally is connected, but is neither live nor on preview. If it is blue (and not flashing), my best guess is that the blue and green color channels on the board are mixed up. The setting [operator.ws2812](https://wifi-tally.github.io/tally.html#tally-settingsini-reference) or switching wires on pin `D1` and `D2` might help.

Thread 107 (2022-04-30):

Change Data pin

Stephan-Kl, 2022-04-30:
Hello,
i have found your solution for a tally light for vMix and its super easy to set up.
I already have build the Tallys with a different software for the atem mini and want to switch to vMix.

The problem is that I soldiers the Neopixel on pin D7.
Is it possible to change pin D4 to D7 in the settings?

Thank you and kind regards
Stephan

czenker, 2022-05-01:
Hi Stephan.

I had to look into it, but unfortunately it does not seem to be possible.

The [underlying library only supports `D4` as UART Pinout](https://nodemcu.readthedocs.io/en/release/modules/ws2812/#ws2812init). The only other option would be to use `TX`, but this would essentially break data over USB.

This is probably something that they should support. But before I open an issue there: Are you sure it is `D7` you are using? According to the pinout `TXD2` is on `D8`.

Stephan-Kl, 2022-05-01:
Hi,
thank you for the fast reply. Unfortunately it is D7 :D so I have to desolder the cables, its niche that difficult but I thought I can change it the easy way ;)

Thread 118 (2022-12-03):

vTally server runs, it works with webtally on another device in the same network, but esp8266 tally doesn't connect to server

L3apr, 2022-12-03:
Hi! I have tried to use an ESP8266 board to connect to v-tally, but it gets stuck on the 2 blinks error code where it doesn't detect vTally, i can access the web-tally trough my phone over the same wifi but the hardware tally doesn't connect at all. I have placed all the necessary lua files and flashed the bin.

Closed 2022-12-03.

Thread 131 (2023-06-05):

OBS Websocket 5 support

sky7176, 2023-06-05:
Good stuf but with a new version of websocket, from OBS 29 and above, this plug-in no longer works.
Are you going to make the necessary changes to get everything working again?

Thank you
Giuseppe

nicolopozzato, 2024-02-12:
So I'm here to ask, I see this project yesterday, I'm now interested on making this for my local church (in some event we use 1 or 2 remote camera, like a smartphone with ndi camera on a smratphone stabilizer) the problem is the comunication from the managment desk to the operator... i really like this project to have a small esp and 2-3 led to notify the camera operator if it's live or in preview. But we use OBS Studio so I don't know now what to do

sergal-IRL, 2024-04-03:
The current version of wifi-tally does not work with OBS version 28.x and above due to the inclusion of obs-websockets 5.0 in that version onwards.

A temporarily fix is to disable the 5.0 websocket server, and install the 4.9.1-compat version from OBS themselves (https://github.com/obsproject/obs-websocket/releases)

iilychy, 2024-12-21:
> The current version of wifi-tally does not work with OBS version 28.x and above due to the inclusion of obs-websockets 5.0 in that version onwards.
>
> A temporarily fix is to disable the 5.0 websocket server, and install the 4.9.1-compat version from OBS themselves (https://github.com/obsproject/obs-websocket/releases)

Seems that 4.9.1-compat couldn't be installed and work properly on Linux, at least on my Ubuntu 22.04 with OBS 30.
I've seen same cases happened too.
https://github.com/obsproject/obs-websocket/issues/1166#issuecomment-2151523584

And contributers of obs-websocket are not gonna fix this bug for now.

So vtally only supports websocket 4, but websocket 4 compat can't be installed on linux. Seems to be dead end.

Is there a way to use vtally without rollback to obs 27 on Linux? Thanks.

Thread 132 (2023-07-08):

lua: my-app.lc: bad header in precompiled chunk

bencius, 2023-07-08:
Hey there. I'm trying to launch your software on ESP8266, and I get this error as all files are uploaded to the board:

`NodeMCU 0.9.5 build 20150318  powered by Lua 5.1.4
lua: my-app.lc: bad header in precompiled chunk`

What I'm doing wrong?

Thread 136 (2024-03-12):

ERROR UPLOAD CODE

manuugonz, 2024-03-12:
Hello!

First of all congratulations for making this work public!

I'm kind of a newbie in all this and I'm having some problems getting my NodeMCU V3 to work.
I have installed the Firmware 0.5.1 .bin file, with the NodeMCU PyFlash app, with 115200 baud settings and in QIO mode with "yes, wipes all data". So far so good!

Once this is done I run ESPlorer v0.2.0 and connect my board, at this moment what I do is with the "Upload" button to load all the .lc files and at the end I load with the same button the init.lua. Then I duplicate the tally-settings.ini.example and rename it to tally-settings.ini where I edit it and put both the ip and the network name, do I also have to upload this file with the upload button or do I have to do something else? I currently do not have an RGB strip and I only have one red and one green and one blue led, is there an option to modify any parameter to see if this works?

When I access the application it does not detect the device. As HUB, I put the ip where the web app is running, right?

I need help, since I have been using it for 4 hours and I can't get it to work.

Thanks

Closed 2024-03-13.

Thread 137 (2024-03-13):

LED DIODE

manuugonz, 2024-03-13:
Hello, is it possible, to change the current configuration and instead of using a RGB led bar, it would be possible to use independent led diodes? Either Red / Green / Blue / White. I would like to put a led only for the connect / preview and live function.

I am keeping an eye on this to make/design a nice box and upload it for everyone to use.

Thanks

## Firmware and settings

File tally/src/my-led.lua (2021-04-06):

--- everything related to making LEDs blink.
--- it serves as a library to everything else

-- pins used for the operators light
local pinOpG, pinOpR, pinOpB = 1, 2, 3

-- the pin that is sometimes connected to an LED on the board
local pinOnBoard = 0

-- pins used for the main light
local pinMainG, pinMainR, pinMainB = 5, 6, 7

gpio.mode(pinOnBoard, gpio.OUTPUT)

-- uses D4
ws2812.init(ws2812.MODE_SINGLE)

-- timer used to make LEDs flash on and off
local timer = tmr.create()
-- setup all the RGB pins as pwm pins
pwm2.setup_pin_hz(pinOpR, 1000, 100, 100)
pwm2.setup_pin_hz(pinOpG, 1000, 100, 100)
pwm2.setup_pin_hz(pinOpB, 1000, 100, 100)
pwm2.setup_pin_hz(pinMainR, 1000, 100, 100)
pwm2.setup_pin_hz(pinMainG, 1000, 100, 100)
pwm2.setup_pin_hz(pinMainB, 1000, 100, 100)
pwm2.start()

--- sets up the color as the current color the Tally should display
--- @param operatorR number [0-255] the brightness of the RED LED for the operator  light
--- @param operatorG number [0-255] the brightness of the GREEN LED for the operator  light
--- @param operatorB number [0-255] the brightness of the BLUE LED for the operator light
--- @param stageR number [0-255] the brightness of the RED LED for the stage light
--- @param stageG number [0-255] the brightness of the GREEN LED for the stage light
--- @param stageB number [0-255] the brightness of the BLUE LED for the stage light
local showColor = function(operatorR, operatorG, operatorB, stageR, stageG, stageB)
    --
    -- DRIVE THE OPERATOR LIGHT
    --
    local operatorDutyR, operatorDutyG, operatorDutyB = operatorR / 255*100, operatorG / 255*100, operatorB / 255*100
    if MySettings.operatorType() == LightTypes.COMMON_ANODE then
        operatorDutyR, operatorDutyG, operatorDutyB = 100 - operatorDutyR, 100 - operatorDutyG, 100 - operatorDutyB
    end
    pwm2.set_duty(pinOpR, operatorDutyR)
    pwm2.set_duty(pinOpG, operatorDutyG)
    pwm2.set_duty(pinOpB, operatorDutyB)

    --
    -- DRIVE THE STAGE LIGHT
    --
    local stageDutyR, stageDutyG, stageDutyB = stageR / 255*100, stageG / 255*100, stageB / 255*100
    if MySettings.stageType() == LightTypes.COMMON_ANODE then
        stageDutyR, stageDutyG, stageDutyB = 100 - stageDutyR, 100 - stageDutyG, 100 - stageDutyB
    end
    pwm2.set_duty(pinMainR, stageDutyR)
    pwm2.set_duty(pinMainG, stageDutyG)
    pwm2.set_duty(pinMainB, stageDutyB)

    --
    -- DRIVE THE WS2812 STRIP
    --
    if MySettings.operatorNumberOfWs2812Lights() + MySettings.stageNumberOfWs2812Lights() > 0 then
        -- the API uses chars to represent brightness
        local data = ""
        if MySettings.operatorWs2812Type() == Ws2812Types.GRB then
            for _=1,MySettings.operatorNumberOfWs2812Lights() do
                data = data ..
                    string.char(operatorG) ..
                    string.char(operatorR) ..
                    string.char(operatorB)
            end
        elseif MySettings.operatorWs2812Type() == Ws2812Types.RGB then
            for _=1,MySettings.operatorNumberOfWs2812Lights() do
                data = data ..
                    string.char(operatorR) ..
                    string.char(operatorG) ..
                    string.char(operatorB)
            end
        end
        if MySettings.stageWs2812Type() == Ws2812Types.GRB then
            for _=1,MySettings.stageNumberOfWs2812Lights() do
                data = data ..
                    string.char(stageG) ..
                    string.char(stageR) ..
                    string.char(stageB)
            end
        elseif MySettings.stageWs2812Type() == Ws2812Types.RGB then
            for _=1,MySettings.stageNumberOfWs2812Lights() do
                data = data ..
                    string.char(stageR) ..
                    string.char(stageG) ..
                    string.char(stageB)
            end
        end
        ws2812.write(data)
    end

    --
    -- DRIVE THE ONBOARD LED
    --
    -- pwm2 does not support to drive pin D0, so we try to emulate the flashPattern as good as possible without PWM
    if (operatorR == 0 and operatorG == 0 and operatorB < 255) or (operatorR == operatorG and operatorG == operatorB and operatorB < 255) then
        -- only turn LED off if a flash pattern in blue color expects it to be off
        -- this causes the LED to be on by default

        -- with common anode HIGH means OFF
        gpio.write(pinOnBoard, gpio.HIGH)
    else
        gpio.write(pinOnBoard, gpio.LOW)
    end
end

local currentFlashHash = nil
--- makes the LEDs blink in a given pattern in the given color
--- @param operatorR number [0-255] the brightness of the RED LED for the operator  light
--- @param operatorG number [0-255] the brightness of the GREEN LED for the operator  light
--- @param operatorB number [0-255] the brightness of the BLUE LED for the operator light
--- @param stageR number [0-255] the brightness of the RED LED for the stage light
--- @param stageG number [0-255] the brightness of the GREEN LED for the stage light
--- @param stageB number [0-255] the brightness of the BLUE LED for the stage light
--- @param pattern boolean[] a table of booleans if the light should be bright (true) or dark (false) in this step
--- @param stepDuration number how long before the next step is shown (in ms)
local showFlashPattern = function(operatorR, operatorG, operatorB, stageR, stageG, stageB, pattern, stepDuration)
    local patternHash = ""
    for _, step in pairs(pattern) do
        patternHash = patternHash .. (step and "1" or "0")
    end
    local flashHash = string.format(
        "%d/%d/%d-%d/%d/%d-%s-%d",
        operatorR, operatorG, operatorB,
        stageR, stageG, stageB,
        patternHash,
        stepDuration
    )
    if flashHash == currentFlashHash then
        -- the same flash pattern is already running.
        -- should not be started again, because it will destroy the visual pattern
        return
    end
    currentFlashHash = flashHash

    local currentIdx = 1
    local maxIdx = #pattern
    local next = function()
        local isBright = pattern[currentIdx]
        if isBright then
            showColor(operatorR, operatorG, operatorB, stageR, stageG, stageB)
        else
            showColor(
                math.ceil(operatorR * 0.3), math.ceil(operatorG * 0.3), math.ceil(operatorB * 0.3),
                math.ceil(stageR * 0.3), math.ceil(stageG * 0.3), math.ceil(stageB * 0.3)
            )
        end

        currentIdx = currentIdx + 1
        if currentIdx > maxIdx then currentIdx = 1 end
    end
    timer:unregister()
    next()
    timer:alarm(stepDuration, tmr.ALARM_AUTO, next)
end
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

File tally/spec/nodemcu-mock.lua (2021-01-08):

_G.node = {
    chipid = function() return 12345678 end
}

_G.file = {
    exists = function() return true end,
    open = function()
        return {
            readline = function(_) return nil end,
            close = function() end,
        }
    end,
}

_G.now = 0 -- current simulated time in seconds

-- tracks the value of the pin by elapsed time
-- a value of 0 means LOW, 1 means HIGH and everything in between indicates the duty cycle of pwm
_G.pinByTime ={
    data = {},
    set = function(self, pin, value)
        local time = _G.now
        if time - math.floor(time) >= 0.5 then
            time = math.ceil(time)
        else
            time = math.floor(time)
        end

        self.data[pin] = self.data[pin] or {}
        self.data[pin][time] = value
    end,
    get = function(self, pin, time)
        local closestTime
        local value
        for theTime, theValue in pairs(self.data[pin]) do
            if theTime <= time and (closestTime == nil or closestTime < theTime) then
                closestTime = theTime
                value = theValue
            end
        end
        return math.floor(value * 100 + 0.5) / 100
    end,
    print = function(self, pin)
        for k,v in pairs(self.data[pin]) do
            print(k, v)
        end
    end,
}

_G.gpio = {
    OUTPUT = "output",
    HIGH = 1,
    LOW = 0,
    modeByPin = {},
    mode = function(pin, mode)
        if mode ~= _G.gpio.OUTPUT then
            error("Only gpio as output pins are supported by the mock.")
        end
        _G.gpio.modeByPin[pin] = mode
    end,
    write = function(pin, level)
        _G.pinByTime:set(pin, level)
    end
}
_G.pwm2 = {
    start = function() end,
    pulsePeriodByPin = {},
    setup_pin_hz = function(pin, freqAsHz, pulsePeriod, initialDuty)
        if (freqAsHz < 100) then
            error("frequencies lower as 100Hz are not supported by the mock. We just assume pwm is used to dim LEDs")
        end
        _G.pwm2.pulsePeriodByPin[pin] = pulsePeriod
        _G.pinByTime:set(pin, initialDuty / pulsePeriod)
    end,
    set_duty = function(pin, duty)
        if _G.pwm2.pulsePeriodByPin[pin] == nil then
            error("Pin " .. pin .. " has not been set up for pwm")
        end
        _G.pinByTime:set(pin, duty / _G.pwm2.pulsePeriodByPin[pin])
    end
}
_G.tmr = {
    ALARM_AUTO = "auto",
    create = function()
        local maxSimTime = 3000 -- abort the mock simulation after this many seconds
        local timerActive = false
        return {
            unregister = function()
                timerActive = false
            end,
            alarm = function(self, delay, type, func)
                timerActive = true
                if type ~= _G.tmr.ALARM_AUTO then
                    error("only type ALARM_AUTO is supported by the mock.")
                end

                _G.now = 0
                while timerActive and _G.now <= maxSimTime do
                    _G.now = _G.now + delay
                    func()
                end
                timerActive = false
                _G.now = 0
            end
        }
    end,
    now = function()
        return 1234567890
    end,
}

_G.ws2812 = {
    data = {},
    MODE_SINGLE = "single",
    init = function(mode)
        if mode ~= "single" then
            error("Only MODE_SINGLE is supported by the ws2812 mock", 2)
        end
    end,
    write = function(data)
        local time = _G.now
        if time - math.floor(time) >= 0.5 then
            time = math.ceil(time)
        else
            time = math.floor(time)
        end
        _G.ws2812.data[time] = data
    end,
    getDataAt = function(self, time)
        local data = self.data[time]
        if data == nil then return nil end
        --@TODO: table.pack would be the way to go in Lua5.3
        local dataStream = {}
        for i=1,string.len(data) do
            table.insert(dataStream, data:byte(i))
        end
        return dataStream
    end,
}

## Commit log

2020-03-11 making it public
    [tally-schematics.fzz]
2020-03-15 log the boot reason of the tally to detect software errors
    [my-app.lua]
2020-05-09 document stage and operator lights
    [tally-schematics.fzz]
2020-05-09 fix broken build after update to mkdocs-material 5.x
2020-05-10 show ok status on operator light
    Resolves #7
    [my-led.lua]
2020-05-10 change pinout
    Resolves #5
    [tally-schematics.fzz]
2020-05-10 use the other LED on the board to indicate program is running
2020-05-10 add flashing pattern when settings file is corrupt
    Resolves #11
    [my-app.lua, my-led.lua]
2020-05-10 support different brightnesses in LED flashing
2020-07-21 do not auto connect mixer connectors
    This makes tests a little easier
2020-07-21 tests for Vmix Connector #12
2020-07-28 move tracking of current program and preview into MixerCommunicator
2020-08-11 Document current drain #14
2020-08-15 use onboard LED to signal errors
    This potentially frees D4 for WS2812 use
    [my-led.lua]
2020-08-19 allow use of LEDs with common cathode #31
2020-08-19 move stage light to pins D1-D3
    This is to free PIN 4 for WS2812 use
    [tally-schematics.fzz]
2020-08-20 kickstart unit tests for my-led.lua
2020-08-21 add tests for operatorType and stageType settings
2020-08-21 support the use of WS2812 strips, NeoPixel and the like #29
    [tally-schematics-ws2812-rgb.fzz, tally-schematics-ws2812.fzz]
2020-08-21 document how to use led with common cathode
2020-08-25 clarify `grb+` and `grb-` as defining the "off" state of a pin #31
2020-08-25 pin nodejs version in build
2020-08-25 push artifacts of every build in an s3 bucket
2020-09-01 corrected "operator.ws2812" into "stage.ws2812"
2020-11-24 prevent vMix from trying to reconnect even after connection was cut
2020-12-20 migrate away from HTTP to socket for frontend information retrieval
2020-12-20 synchronize tallyand channel state via socket
2020-12-20 sync tally logs via socket
2020-12-20 unfetch is nolonger needed as we use sockets for server-client communication
2020-12-22 replace bootstrap with material UI
    it seems the better ui framework to work with
    react
2020-12-23 drop next.js :tada:
    It did not benefit us in any way. We did not use any of its
    features and Server Side Rendering was even a hinderance, because
    we needed to ship every frontend library, @babel, @material-ui, etc
    with each release. This made the release size explode.
2020-12-26 fix case of data-testid
2021-01-08 switch the protocol so that Tally only knows which color to show
    this was necessary as NodeMCU ran out of memory :(
2021-01-08 allow to configure if stage light shows the preview state
2021-03-09 support WS2812 leds with red-green-blue order #52
2021-06-05 allow package to be used on arm architectures
